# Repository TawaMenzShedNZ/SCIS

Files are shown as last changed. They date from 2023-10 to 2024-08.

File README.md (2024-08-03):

SCIS Shed Check-In System
===============

This is a management utility to track User signins / signouts and manage machine access.

(c) Tawa Menzshed 2024

Overview
-------------
This utility provides a central point for signing in and signing out of the workshop using RFID Fobs / Cards.
It also allows for Users' Fobs to be authorised to use equipment attached to a Device Access Box with a scanning mechanism.

Features
-------------
* Tracking of signins and signouts
* Database of Contact details for users
* Access Control for Devices attached
* Reporting on Access Dates / Times / Devices

Upcoming Changes
-------------
Enhancements coming for higher amperage Devices and better access management rules (sometime 2025).

Questions / Queries
-------------
Contact scistechnician49@gmail.com

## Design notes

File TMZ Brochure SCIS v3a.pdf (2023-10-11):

# Shed Check-In System

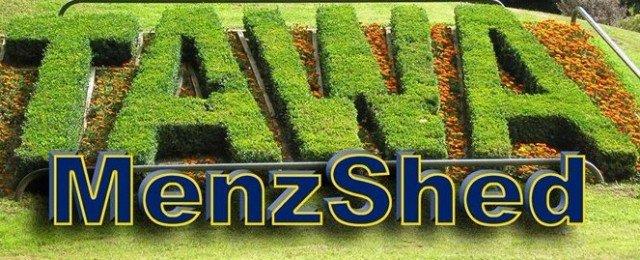
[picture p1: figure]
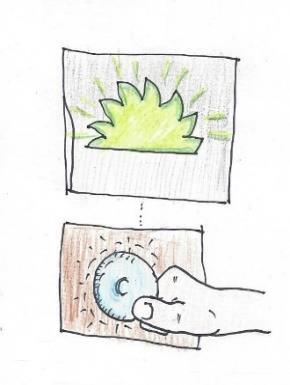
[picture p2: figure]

What is it? | A computerised System for tracking shed member attendance of Users, authorise member use of designated electrical equipment, identify when breakages occur and facilitate safety training.
Who can use it? | Any organisation that wants to know who is onsite, who is using machinery and what safety training is needed.
What does it use? | The system comprises 4 types of devices • a small PC for management • a sign-in box • one or more access boxes • a wireless router for communications

How does it work?

A small PC acts as a central server, and communicates with a sign-in device and one or more access boxes. The devices and boxes are using small Arduino computers which talk through the wireless router to the central server. Each Arduino has a swipe sensor reader to identify the user and validate their access. If a breakage occurs, the last user is known.

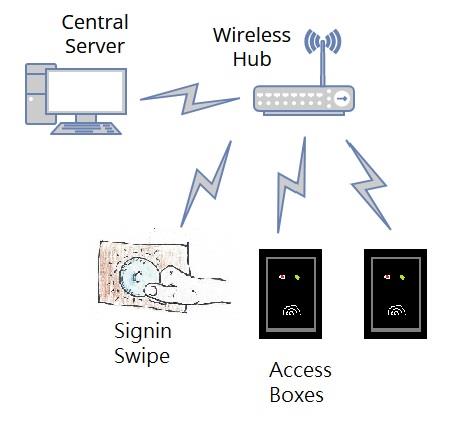
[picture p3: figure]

Would you like to know more?

Bookmark the github entry for the system at https://github.com/TawaMenzShedNZ/SCIS. An initial release of the code, build plans and documentation should be released in the first half of 2024.

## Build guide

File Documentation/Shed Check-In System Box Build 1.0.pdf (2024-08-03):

Shed Check-In System Access Box Build Procedure | Version 1.0

# Shed Check-In System Access Box Build Procedure

## Version 1.0

Author: Ian Dennison
Tawa MenzShed
Date: 07/07/2024
Version: 1.0

# Table of Contents

## Contents

# 1 Introduction

### 1.1 Document Purpose

This document describes the physical build and software installation of the Shed Check-In System (SCIS) Sign-In and Access Boxes.

### 1.2 Intended audience

This document is intended to be read and used by people with relevant technical knowledge (microelectronics, Arduino programming, and computer networking). Sheds wishing to implement this should seek out members or associates who have the required skills. For more details, refer Skills Requirement section in primary Shed Check-In System Manual.

### 1.3 Architecture

The SCIS Client Images are designed to run on WEMOS D1 Arduino Devices, with a built in WIFI component. Both the Sign-In / Sign Out Box and the Device Access Box are configured to run on these devices.

### 1.3.1 Sign-In Box

The Sign-in Box is a single box that is used for registering User sign-ins and sign-outs. It is also used to validate Administrators for access to the Admin functions of the System, so should ideally be placed near the Central Server.

### 1.3.2 Device Access Box

The Device Access Boxes are used for validating a User request and granting or denying access to a specific device (machine).

Each Access Box is identified by a unique identifier called a WWN, which is derived from the network chip on the Arduino device. This is matched up to the configuration inside the Central Server to provide access to the hardware attached to the Access Box.

When building the Device Access Box, your Power Relay will one of two types:

i) High – when the current applied is High, the access is opened

ii) Low – when the current applied is Low, the access will be opened

The current catered for at the moment is 10A, with a control voltage of 3.3V (matching the Arduinos voltages).

### 1.4 Preparation

### 1.4.1 Hardware Requirements – Sign-In Box

For the Sign-In/ Sign-Out Box, you will need the components listed in Appendix A. This box can be powered by a longer USB Cable connected to an external power supply (It may be possible to power it from a spare USB port on the Central Server itself).

Photo 1 – External View of Swipe Box

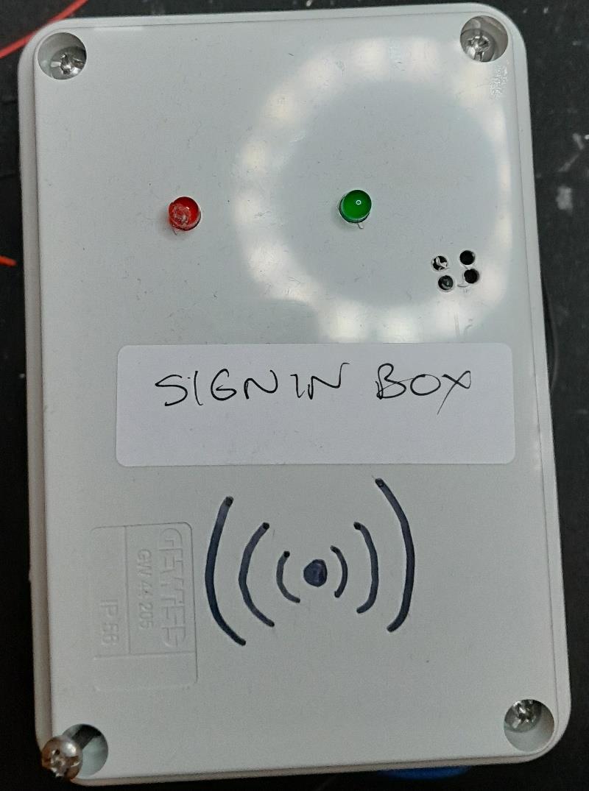
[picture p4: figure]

Photo 2 – Internal View of Swipe Box

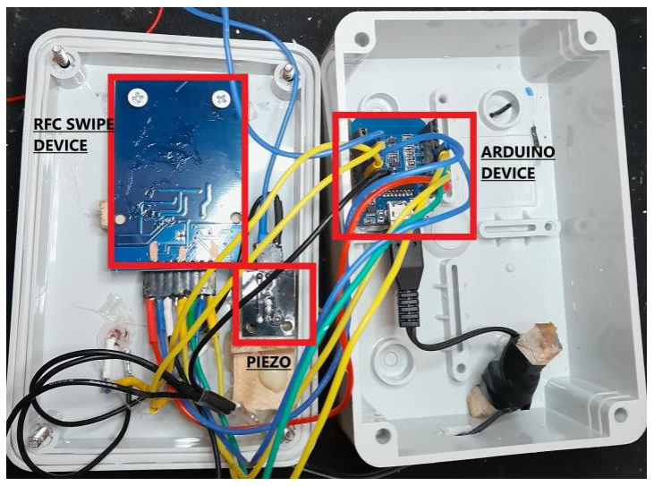
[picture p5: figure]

### 1.4.2 Hardware Requirements – Device Access Box

For the Sign-In/ Sign-Out Box, you will need the components listed at Appendix B.

The Device Access Boxes do involve more components so can compete for internal space. It is recommended to add an intermediate plug for the 2 x LEDs to allow the top of the device to be removed for maintenance. Also leave the bottom left area free, as future releases may use this space.

Photo 3 – Device Access Box (Top Cover)

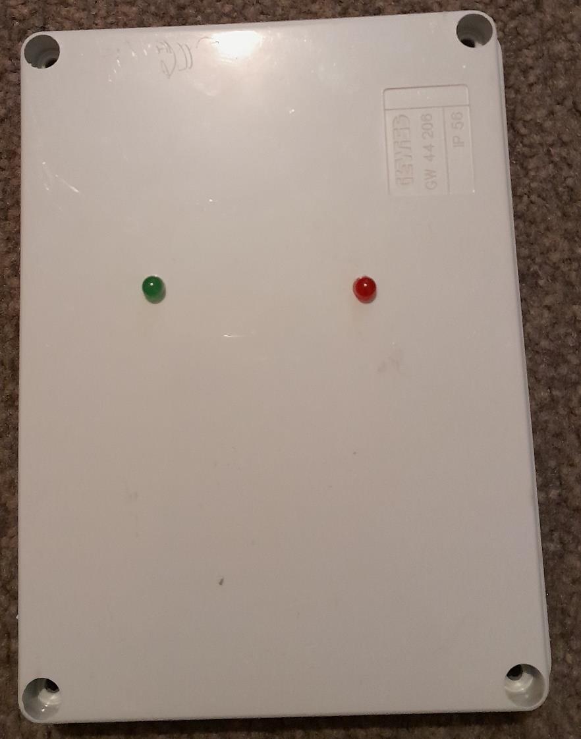
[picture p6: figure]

Photo 4 – Device Access Box (Top underneath)

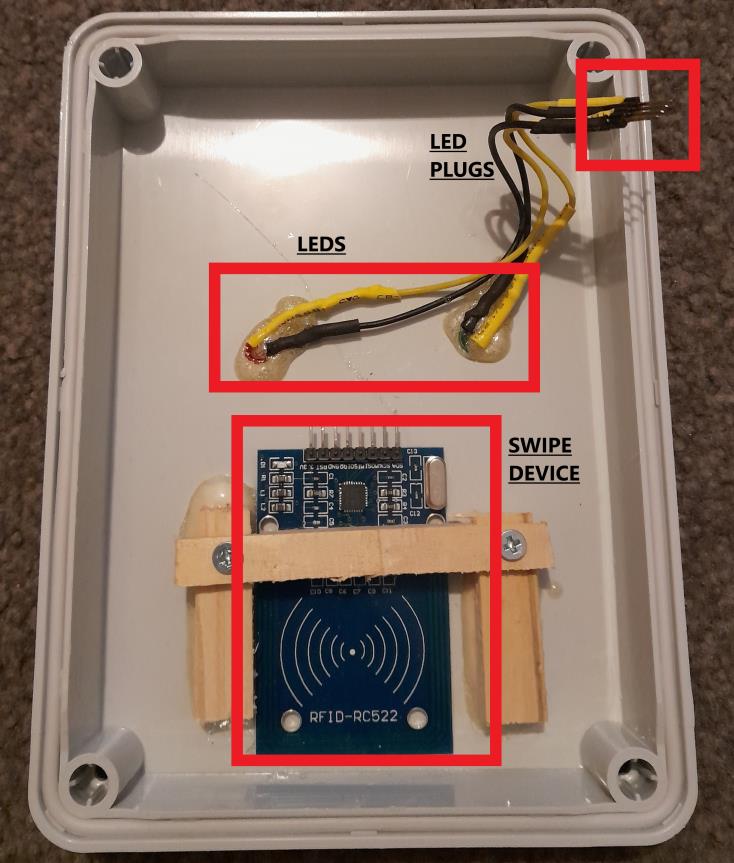
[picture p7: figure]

Photo 5 – Device Access Box (Body) – cables removed for clarity

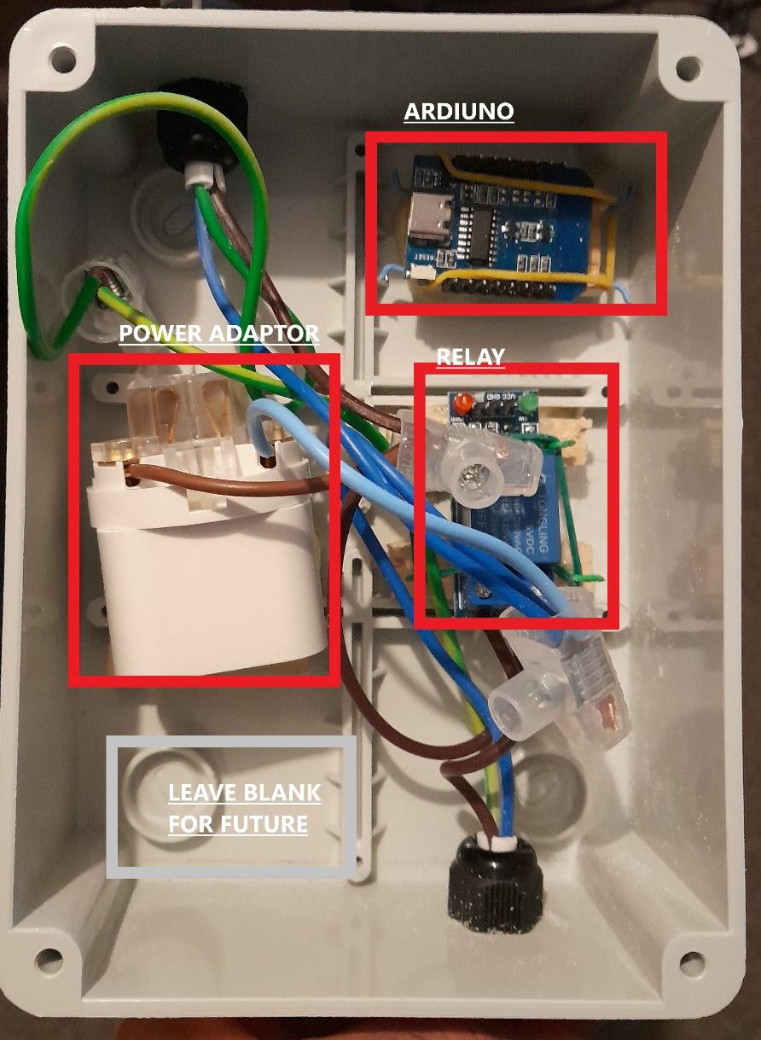
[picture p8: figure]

### 1.4.3 Software Requirements

There are 2 main images for the Device Access Arduino, depending on the type of Relay being deployed. At present, it is trial-and-error on which image is required, but an incorrect image should not damage the device (be sure to test before installing the Device Access Box).

Field | Rationale
machine_box_WWN_High.ino | Works on the WWN based addressing and activates Relay when current is High
machine_box_WWN_Low.ino | Works on the WWN based addressing and activates Relay when current is Low

In order to read the Wiring Diagrams for the Boxes, you will need the following software:….

i) Adobe Acrobat – This is the free reader application for PDF Files. It can be downloaded from https://get.adobe.com/reader/. It also comes bundled in newer web browsers.

ii) Fritzing – This circuit layout software is required if you wish to modify the .fzz sketches that are included as part of the Software Bundle and also included in PDF form for easy viewing. It can be downloaded from https://fritzing.org/.

To manage the Arduino devices and download the images and drivers, you will need the following software on a windows-based device.

iii) Arduino IDE – This is the software needed to manage the Arduino Devices and deploy the images to the Arduinos. It can be downloaded from https://www.arduino.cc/en/software.

### 1.5 Build

The attached PDF plans (taken from the Fritzing Images) should detail the layouts for cabling and connections, between the various components. Included are plans for Sign-in Boxes and Device Access Boxes.

This document assumes that you already know how to solder, cable and mount components to build an electronic project. A list of recommended tools and ancillaries are listed in Appendix D but are not exhaustive.

### 1.6 Good Practice Recommendations (Device Access Boxes)

- Power Cables – put these entry points offset from centre, to allow space for other electronics
| to fit in. Typically leave 60 cms of cable in for the plug end and 30 cms of cable to the socket end.
- Swipe Sensors – Place these hard up against the top cover of the box, even a gap of 5-8mm
| will make it difficult to read. Also mark the external location of the sensor to direct the user where to swipe.
- Wemos D1 – always purchase the variant with the requirement to solder the connectors, and
| chose the shorter as these fit the connectors better (longer pre-made connectors can push the connectors out of the surround).
- Relays – always connect incoming Phase Power Wire to “COM” (Common) and outgoing
| Phase Wire to “NO” (Normally Open).
- Relays – Always tin the wires that go into the control sockets of the relay for screw-down
| attachments.
- Relays – Option “H” should be selected on the Relay Jumpers.
- Mounting brackets – Wooden standoffs for securing components are cheap and easy to
| make. Future releases of this tool may include 3d printing patterns for custom mounting brackets.
- Connections – Use a hobby glue gun for components you may wish to remove and replace.
| For more permanent connections, it is recommended to use Tarzan’s Grip glue.

### 1.7 Software Deploy

### 1.7.1 Arduino IDE Software and Drivers

Download and install the Arduino IDE.

For Board Drivers, start the Arduino IDE on an internet connected computer and navigate to “File” – “Preferences. In the field “Additional Board Manager URLs:” add the entry http://arduino.esp8266.com/stable/package_esp8266com_index.json and close with OK.

Navigate to “Tools” – “Board” - “Boards Manager” and search for “esp8266” in the text field. Select the “Install” button.

Photo 6 – ESP8266 Package

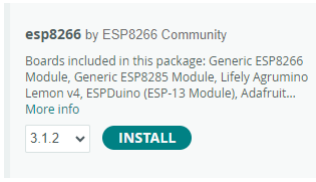
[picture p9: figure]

For Reader Libraries, select “Tools” – “Manage Libraries”. Enter the text “MFRC522” and select “Install” button.

Photo 7 – MFRC522 Package

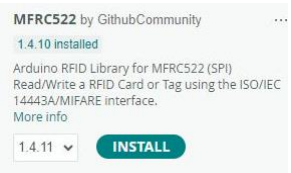
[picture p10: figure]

### 1.7.2 Customising the Arduino Image

In order to connect to your system, you will need to specify some of your local parameters.

Start the Arduino IDE and open the Image you wish to deploy using “File” - “Open” and selecting the relevant “.ino” file. You will need to update the following parameters…

Field | Rationale
ssid[] | The identifier of your Wifi Router
password[] | The password of your Wifi Router
port | Should stay at 80

Photo 8 – network parameters

### 1.7.3 Arduino Device Setup and Image Deploying

Start the Arduino IDE and connect the Arduino Device via USB.

Drop down the Board Box and you should see a COM Port assigned to the Device.

Photo 9 – Board Box Selection

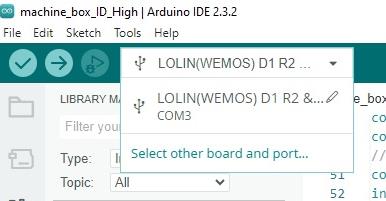
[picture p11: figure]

If it says “UNKNOWN”, click on the device and select Board Type of “LOLIN(WEMOS) D1 R2 & mini”.

To deploy the image to the Arduino, first open the image using “File” – “Open” and select the “.ino” file. Select the right arrow symbol on the toolbar to deploy the image (see above)

To monitor the output, the Serial Monitor needs to be open. Select the Magnifying Glass on the top

right of the screen to open this.

You will need to select the baud rate of the communications channel inside the Arduino, we recommend you use 115200. Otherwise you may see the response below.

Photo 10 – unprintable characters

You may need to perform a reset on the Arduino to see traffic (button next to USB connection).

### 1.7.4 Arduino Messages

The Arduino produces some messages not visible using normal operation but which can be viewed when connected to a Windows host with Arduino IDE installed.

Initial Setup

When starting up, the Arduino will alternately flash the LEDs until it can login to the Wifi. The messages below are a normal startup.

Photo 11 – normal startup

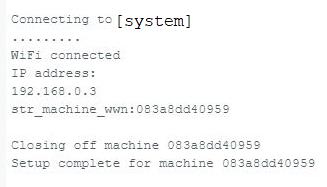
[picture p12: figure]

Access Denied

When a swipe is detected, the Arduino will send a web call to the Central Server with the Tag ID being swiped and the WWN of the Arduino, and the server will return a code of 0 for access denied or 1 for access approved. If no signal is received in 2-3 seconds, it will be assumed that access is denied.

Photo 12 – Access Denied

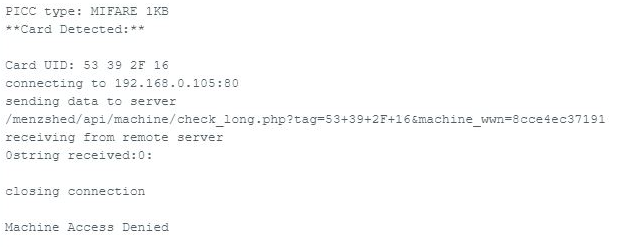
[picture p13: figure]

Access Accepted

When access is granted, the response from the Server will look similar to the text as follows…

Photo 13 - Access Granted

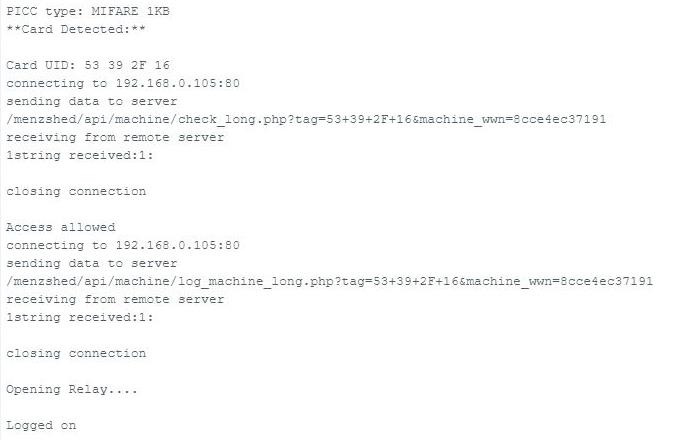
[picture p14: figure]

### Appendix A – Sign-in / Sign-out Box Hardware Components Recommendation and Costs

Component | Description | Indicative Cost
Arduino Device | Wemos D1 Mini with ESP8266 chip | $9 (Trademe NZ)
Swipe Device | RFID RC522 sensor kit | $20 (Trademe NZ)
USB Cable* | 2.0m Cable (check if Micro USB or USB-C, depends on model of Arduino) | $20 (most stores)
Enclosure | 155mm x 115mm x 75mm | $40 (J.A. Russell NZ)
Resistors | 2 x 150 Ohm resistor | $2 (Jaycar NZ)
LEDs | 1 x Red, 1 x Green (5mm, 20mA) | $4 (Jaycar nz)
USB Power | 5V 2A Mains Power Adaptor | $15 (PB Tech)

### Appendix B – Device Access Box Hardware Components Recommendation and Costs

Component | Description | Indicative Cost
Arduino Device | Wemos D1 Mini with ESP8266 chip | $9 (Trademe NZ)
Swipe Device | RFID RC522 sensor kit | $20 (Trademe NZ)
USB Cable* | 0.5m Cable (check if Micro USB or USB-C, depends on model of Arduino) recommend braided with small bend raduis | $20 (most stores)
Relay (3.3V 10A) | Capable of 240V AC, model BESTEP JQC3F-03VDC-C | $5 (epartners.co.nz)
Enclosure | 155mm x 115mm x 75mm | $40 (J.A. Russell NZ)
Resistors | 2 x 150ohm resistor | $2 (Jaycar NZ)
LEDs | 1 x Red, 1 x Green (5mm, 20mA) | $4 (Jaycar nz)
Power Cable | 2m extension cable | $4 (Bunnings NZ)
Enclosure (Power) | Arlec IP44 Outdoor Cord Safety Box | $4 (Bunnings NZ)
USB Power | 5V 2A Mains Power Adaptor | $15 (PB Tech)
AC Plug Socket | 3 pin 240V Female, For USB Power | $10 (Trademe NZ)

### Appendix C – Ancillary Tools / Supplies Required (not complete)

Component | Description

Soldering Iron

Soldering Station | With magnifying glass

Electrical Cable

Heat Shrink

Hookup Cable (24AWG)

240V insulated connectors

Wire Strippers

### Appendix D – Pictures of Common Parts

In order to prevent confusion when ordering online, the required images are shown for the required components.

Component | Image

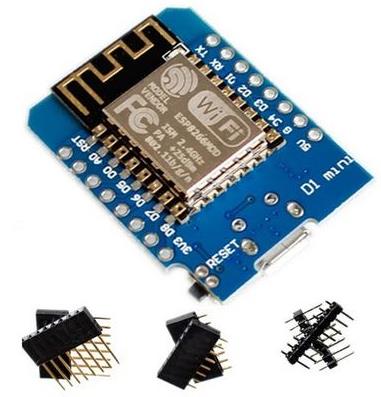
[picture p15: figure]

WEMOS D1 Arduino Device

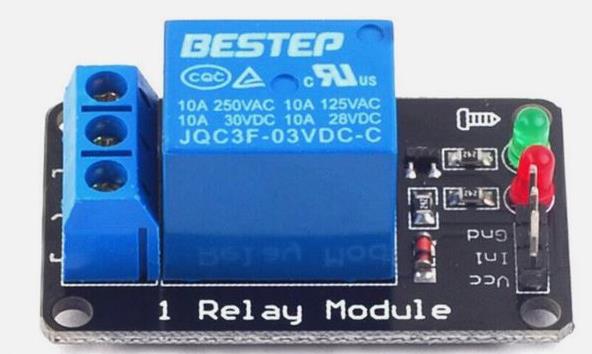
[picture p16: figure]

3.3v 10A Relay

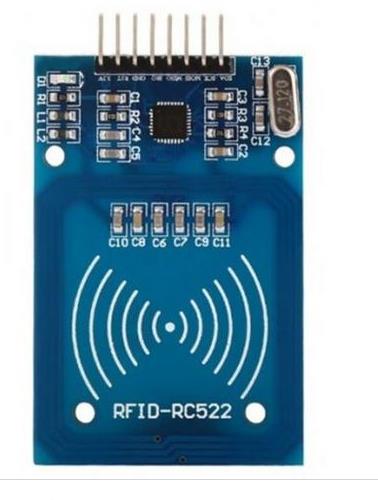
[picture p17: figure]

RFID RC522

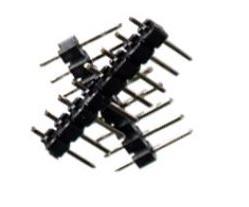
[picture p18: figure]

Shorter Male Prongs (recommended)

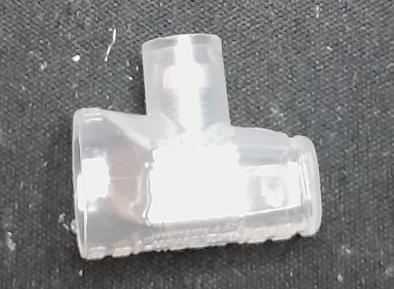
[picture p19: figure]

240V electrical connector

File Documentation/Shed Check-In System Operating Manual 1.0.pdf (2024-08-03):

Shed Check-In System Operating Manual | Software Version 1.0
Page | 1 of 21

# Shed Check-In System Operating Manual

## Software Version 1.0

Author: Ian Dennison
Tawa MenzShed
Date: 07/07/2024
Version: 1.0

Shed Check-In System Operating Manual | Software Version 1.0
Page | 2 of 21

# Document Information

# Table of Contents

# Contents

Shed Check-In System Operating Manual | Software Version 1.0
Page | 3 of 21

Shed Check-In System Operating Manual | Software Version 1.0
Page | 4 of 21

# 1 Introduction

### 1.1 Document Purpose

This document describes the management and use of the Shed Check-In System (SCIS) version 1.0, released on 7/7/2024.

### 1.2 Intended audience

This document is intended for Administrators who wish to use the features of System Checkin / Checkout and Device Access Control on their environment.

A working knowledge of IT systems (Command Line, Web Browser Usage, Networking) is required for managing this System

### 1.3 System Purpose

The Shed Check-In System is an attendance register and machine access management system that automates attendance recording, machine access authorisations and actual machine access.

By maintaining the access register, an Administrator can record machine usage, confirm user attendance and control machine access. This can be used to ensure adequate training on equipment before it is used, and providing accountability in the event of damage or abuse of equioment.

### 1.4 System Architecture

The Shed Check-In System uses a Client / Server architecture. It maintains a record of Member Details, Access Box Details, Access Permissions and Sign-in / Sign-out actions. It uses wireless technology to communicate between the Access Boxes and Central Server.


Shed Check-In System Operating Manual | Software Version 1.0
Page | 5 of 21

### 1.4.1 Central Server

This is a Unix Host running an Apache Web Server and MySQL Database. It manages the function of tracking sign-ins and authorisations for usage of Machines.

### 1.4.2 Signin / Signout Swipe

This is a wireless Arduino device with an RFC Reader that interfaces with the Central Server to record sign-ins and sign-outs. There should only be one Signin Swipe per system and it should be co-located with the Central Server where-ever possible.

### 1.4.3 Access Boxes

These are wireless Arduino devices with an RFC Reader and a Power Relay, that enables or disables power to the connected Tool. These can be identified by a Device ID, or the unique Device WWN derived from the Network component of the Arduino device.

There are 4 basic images that the Access Boxes may use are:

Field | Rationale
machine_box_WWN_High.ino | Works on the WWN based addressing and activates Relay when current is High
machine_box_WWN_Low.ino | Works on the WWN based addressing and activates Relay when current is Low

The “WWN based addressing system” is where the Device ID / Machine ID is assigned at the Central Server, but a link is made between the Device ID on the Server and the unique WWN of the Device Access Box. This allows the same Arduino image to be used on all Device Access Boxes and for swapping of Boxes to be performed by an Administrator rather than requiring a Technician.

### 1.4.4 Network Router

This is a Home Hub device designed to provide IP Addresses and wireless connection between Arduino devices and the Central Server.

### 1.5 Definitions

Term/Acronym | Definition/Full Description
DHCP | Dynamic Host Control Protocol.
DNS | Domain Name System.
Fob | An RFID device (usually round) that is used to identify a User. An alternative to a swipe card..
FQDN | Fully Qualified Domain Name.
HTML | HyperText Markup Language.
MD5 | Message Digest. Used to verify data integrity of the CDSF, and during the initial DSMS System deployment.
NTP | Network Time Protocol.
Perl | A computer programming language
RHEL | Red Hat Enterprise Linux.
root (userid) | The super-user / administrator userid on the Linux system

Commented [JB1]: Sorted table alphabetically by term

Shed Check-In System Operating Manual | Software Version 1.0
Page | 6 of 21
SFTP | Secure File Transfer Protocol. A secure method of file transfer between two systems. SFTP is a subsystem of SSH.
SSH | Secure Shell. A secure method of communication between two systems.
Swipe Card | An RFID Device (usually white and flat) used to identify a User. An alternative to a fob.

Shed Check-In System Operating Manual | Software Version 1.0
Page | 7 of 21

# 2 Installation

### 2.1 System Requirements

### 2.1.1 Host Server Requirements

The SCIS System is made from a collection of common components and requires a common system to run it, often referred to as a LAMP stack - that is, Linux, Apache, MySQL, Perl. The System Requirements below should therefore be considered as confirmed working defaults rather than minimum requirements. Depending on the computing equipment available to you and your level of knowledge, you may wish to use alternative configurations.

### 2.1.1.1 LinuxLite

The system is known to work on Linux Lite 6.4 (Website https://www.linuxliteos.com/index.html). This release is free for non-commercial use. The Linux operating system will require an active internet connection to download any additional software while the Application is installed. After that, it is recommended to host the system on a dedicated network with no connection to the wider internet.

You will require root access on the DSMS Server for the initial setup.

### 2.1.1.2 Apache 2

Apache, due to its widespread use and stability, is the only web server that the SCIS Application has been tested and confirmed working on. Apache 2 should be installed from your distribution’s base repository. No support is offered for alternative configurations..

### 2.1.1.3 Mysql (aka Mariadb)

Mysql is a relational database product that can store data as used by SCIS. Mysql should be installed from your distribution’s base repository.

### 2.1.2 Tarball Contents

A custom script is used to deploy the tool, and this is combined into a “tarball” along with the necessary Web Files and Database schemas.

Directory | Contents
./ | Basic install scripts
./var_www_html | Web pages and scripts
./mysql | Database Creation Scripts

### 2.1.3 Skills Requirements

Some technical skills will be required to install the SCIS System and build and deploy the Swipe System Boxes.

Skill | Requirement
Computer – Hardware | Procuring and Assembling Hardware Managing Boot Process Basic Network / Router Configuration
Computer – Software | Navigation of Menu and File Paths Modification of Files

Shed Check-In System Operating Manual | Software Version 1.0

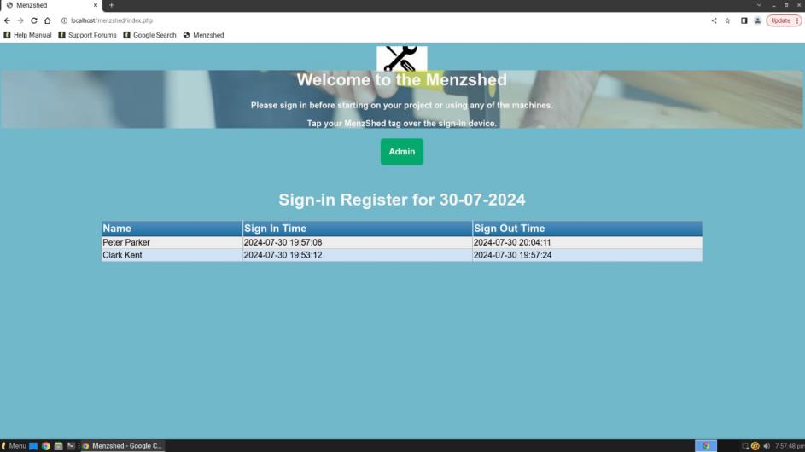
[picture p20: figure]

Page | 8 of 21
| File Transfer and Session Management
Electronics | Component Identification Soldering and Cabling
Electrical | Wire Stripping and Connection Cabling standards

WARNING! Electrical work is covered by different codes in different administrative environments. Make sure you adhere to the rules for your jurisdiction. Electricity can kill!

### 2.2 SCIS Central Server Installation

See separate documentation for SCIS Server Installation.

### 2.3 SCIS Signn and Device Access Box Setup

See separate documentation for SCIS Sign In and Device Access Box Installation.

### 2.4 SCIS Administration

### 2.4.1 Initial Setup

Once the Application has installed, login to the Server itself, start your web browser and navigate to the site http://localhost/menzshed/. You should be presented with the following screen which shows logins and logouts for the current day.

Clicking on “Admin” will take you to the validation screen

Shed Check-In System Operating Manual | Software Version 1.0

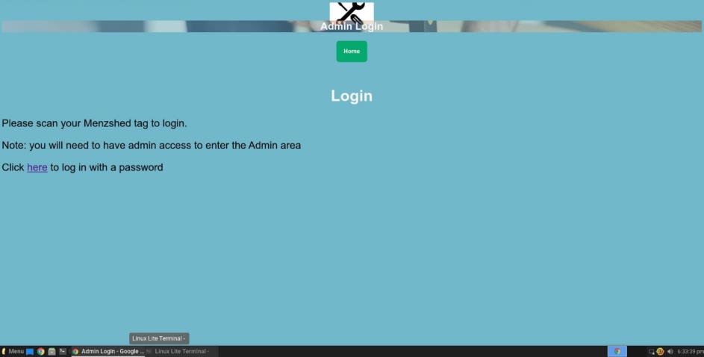
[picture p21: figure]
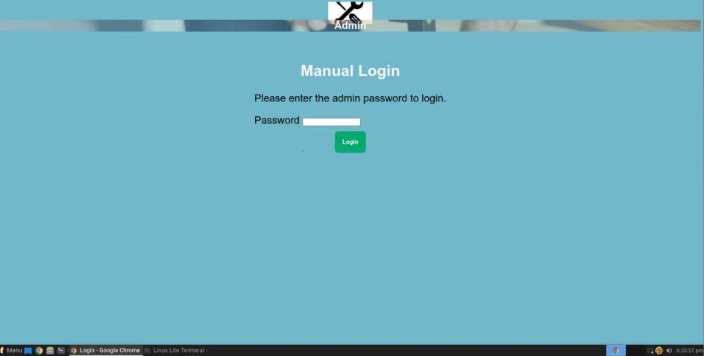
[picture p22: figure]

Page | 9 of 21

Enter your 4 digit passcode from the installation. If you have set up Users already with Administration rights, they can swipe on the signin box instead to gain access.

This is the default Admin Screen presented.

### 2.4.2 Default Administration Screen

This is the main administration screen where the System can be maintained. It is made up of the Header area (where the icons are shown), the Body area where content is displayed, and the Footer area where messages are displayed.

Shed Check-In System Operating Manual | Software Version 1.0

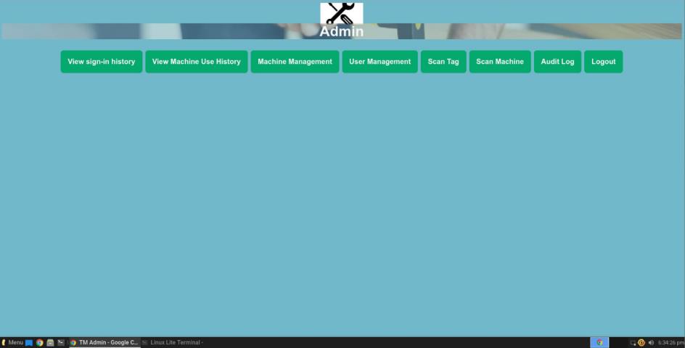
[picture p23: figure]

Page | 10 of 21

The areas are as follows…

Option | Description
View sign-in History | Provides list of sign-ins and sign-outs for users
View Machine Use History | Shows the machine usage log for users, including failed attempts at access
Machine Management | Management of Machine Configuration
User Management | Maintenance of Users and their rights
Scan Tag | Used to identify Tag IDs
Scan Machine | Allows identification of Access Box WWNs
Audit Log | Display logs of machine current load levels (not enabled in this version)
Logout | Logs out the Administration User from the session

### 2.4.3 User Administration

Select the “User Management” icon to display the User Administration screen. This will show a list of current users with a summary of their information.

Shed Check-In System Operating Manual | Software Version 1.0

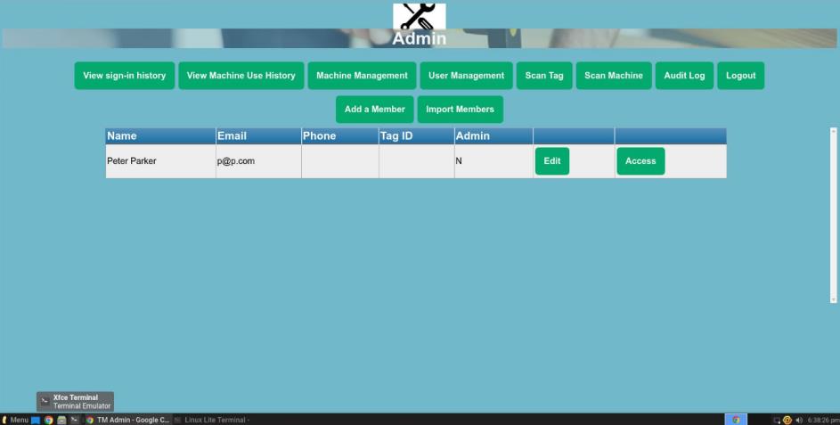
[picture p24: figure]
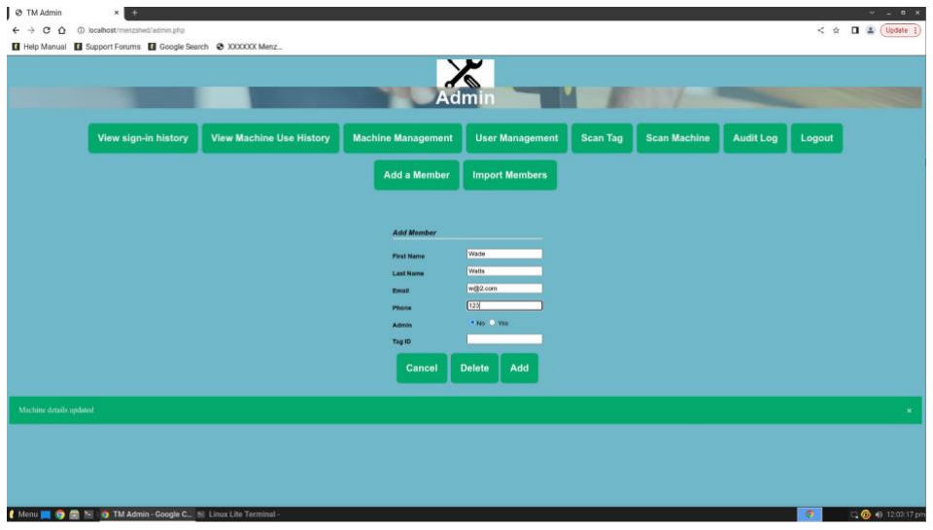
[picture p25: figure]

Page | 11 of 21

### 2.4.3.1 Adding a User

Select the “Add a Member” icon and the following screen will be displayed.

The following fields will be displayed:
- First Name: The First Name of the User
- Last Name: The Last Name of the User
- Email: The Email Address of the User (optional)
- Phone: The Phone Number of the User (optional)
- Admin: Whether the User is an Administrator or not
- Tag Id: The Tag ID of the User (to be filled in later)

Select the “Add” Icon to add the user to the system.

Shed Check-In System Operating Manual | Software Version 1.0

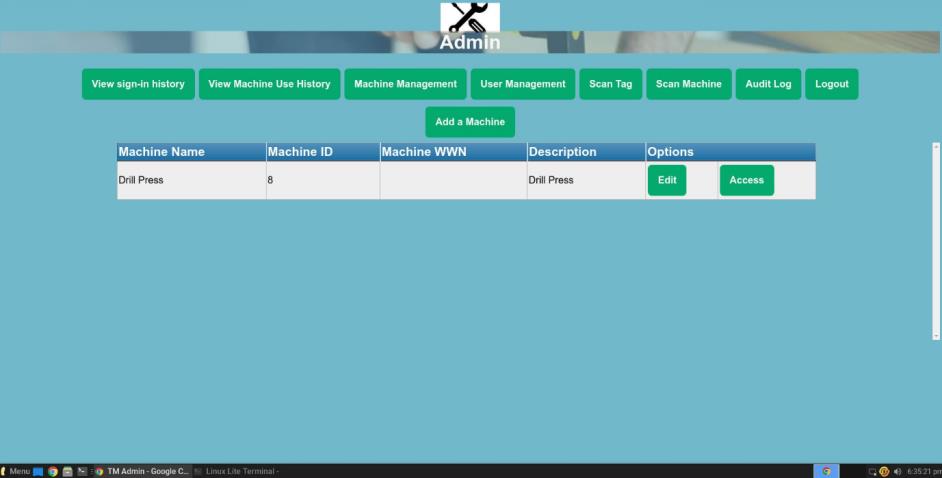
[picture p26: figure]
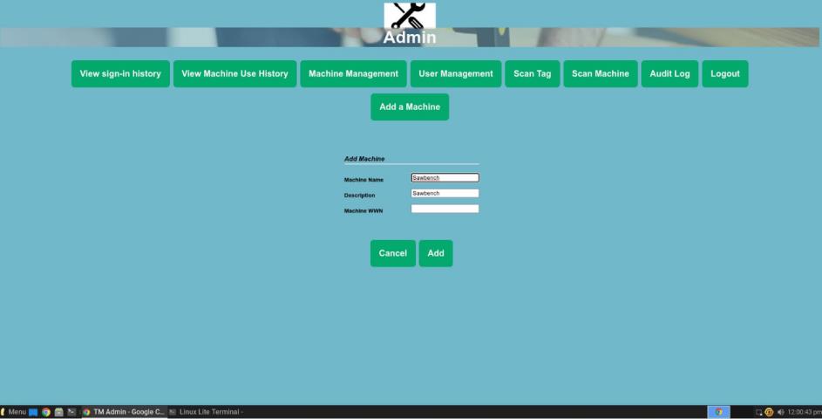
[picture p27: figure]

Page | 12 of 21

### 2.4.3.2 Modifying a User

To modify the User, select the “Edit” icon on the list of Users under “User Management”. The same screen for adding should be displayed with the existing values. Select “Update” icon to confirm the changes.

### 2.4.3.3 Deleting a User

To delete a User, select the “Edit” icon on the list of Users next to the required User, and select the “Delete” icon.

### 2.4.4 Machine Administration

To display the Machine Administration screen, select the “Machine Management” icon from the header.

### 2.4.4.1 Adding a Machine

To add a Machine, select the “Add a Machine” icon. You will be presented with the following screen.

Shed Check-In System Operating Manual | Software Version 1.0

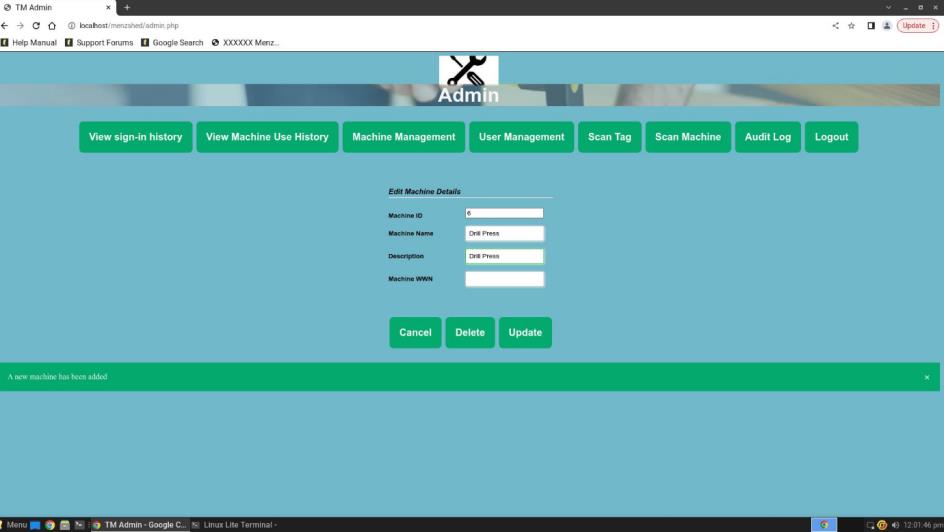
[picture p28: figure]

Page | 13 of 21

The following fields will be displayed:,….
- Machine Name: The name of the Machine
- Machine Description: Long form name of the Machine
- Machine WWN – The unique ID of the Access Box connected to the Machine (optional)

To add the Machine, select the “Add” button.

### 2.4.4.2 Modifying a Machine

To modify a Machine, select the “Edit” button on the Machine List, you will be presented with the following screen. Now the machine is present, the Machine ID will also be displayed.

### 2.4.4.3 Deleting a Machine

To delete a Machine, select the “Edit” button next to the machine and the “Delete” button on the Edit screen.

### 2.4.5 User and Machine Registration

### 2.4.5.1 User Registration

To assign a Swipe Card or Fob to a User, logon as an Administrator to the Central Server and select the “Scan Tag” button.

You will be presented with the following screen.

Shed Check-In System Operating Manual | Software Version 1.0

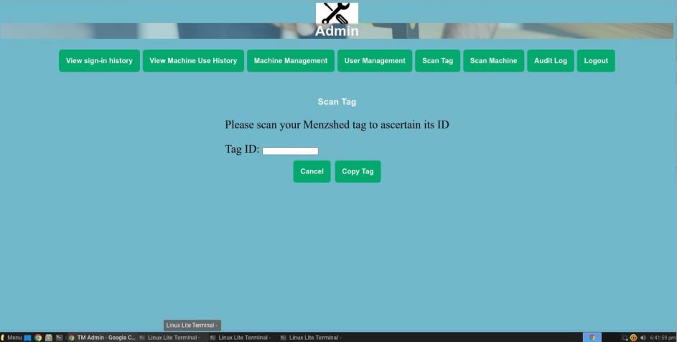
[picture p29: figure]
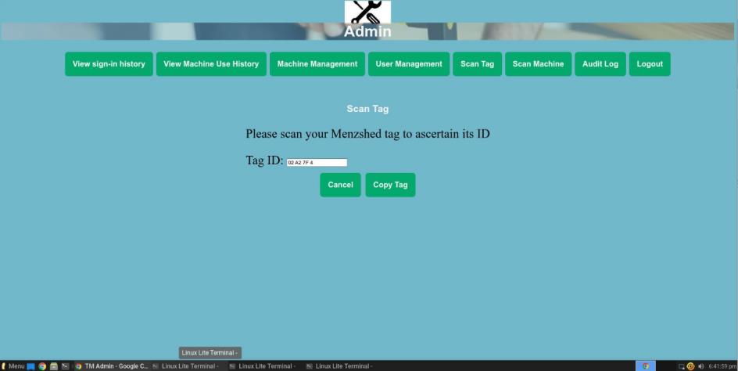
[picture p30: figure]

Page | 14 of 21

On the Sign-in Box, swipe the Fob to be assigned. After a 1-2 second interval, the unique ID of the Fob will be displayed on the screen. Select the “Copy Tag” button to copy the Tag ID into memory.

Navigate to the User using the “Edit” function of the “User Management” screen. You can then paste the copied ID to the “Tag ID” field using keys [Control]-V, and update the User with the “Edit” button.

Shed Check-In System Operating Manual | Software Version 1.0

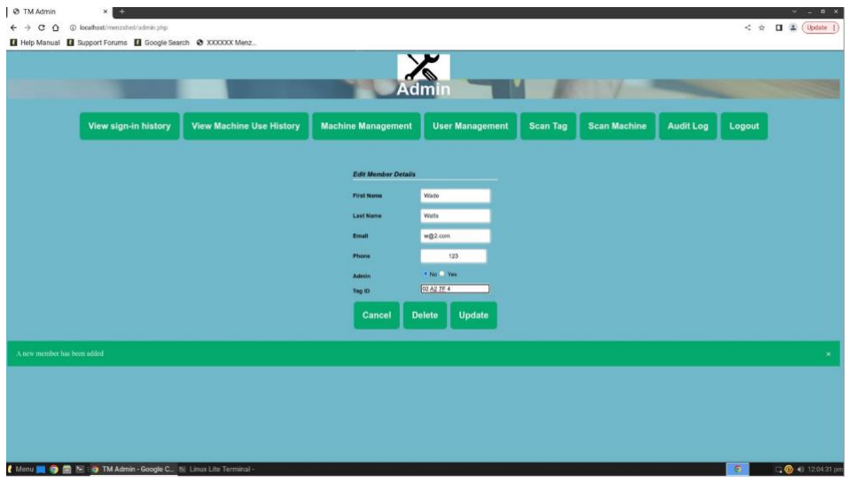
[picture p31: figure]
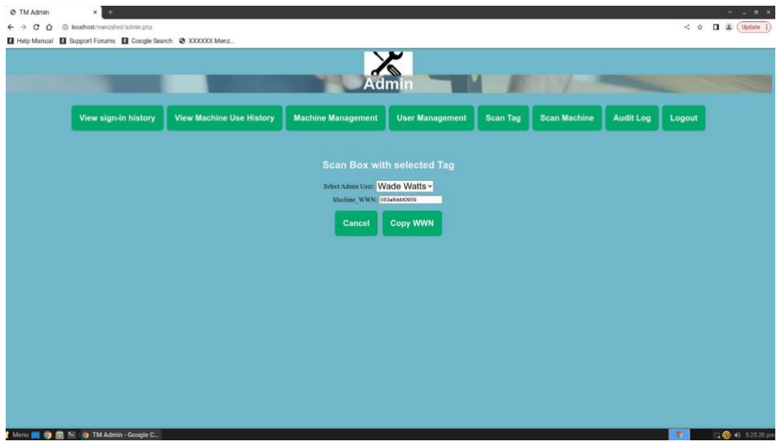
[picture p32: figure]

Page | 15 of 21

### 2.4.5.2 Machine Registration

NOTE: This only applies if using a WWN based image on the Device Access Box.

Log into the Admin Area using an Administrator Fob, and navigate to the “Scan Machine” Screen. From the drop-down box, select the Administrator whose tag will be used to identify the Device Access Box. Once this is selected, the screen will refresh every 2 seconds with the latest Device that the Administrator has swiped against.

To place the Machine WWN discovered into the Copy buffer, select the “Copy WWN” button.

Now navigate to the Machine Management screen and “Edit” the required machine. Paste the WWN into the “Machine WWN” field using [Control]-V and select “Update”. The system will validate the WWN and if it is used elsewhere, it will prevent you from committing the update.

Shed Check-In System Operating Manual | Software Version 1.0

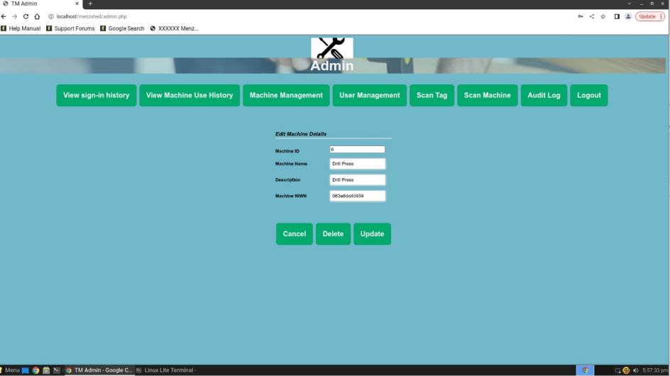
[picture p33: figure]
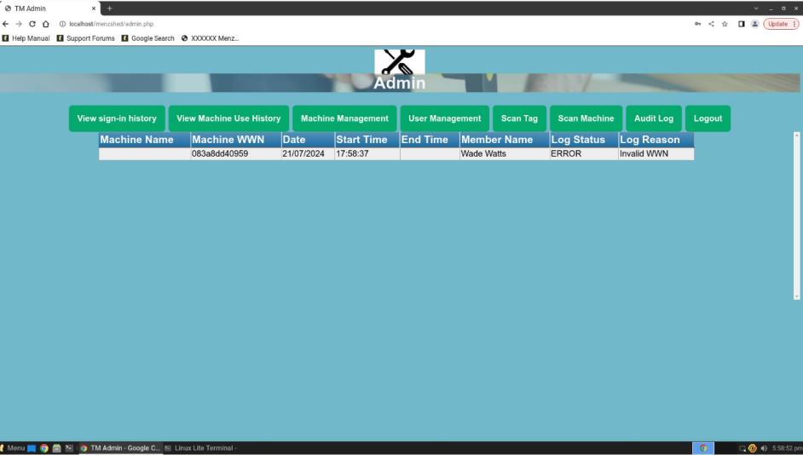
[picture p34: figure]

Page | 16 of 21

NOTE: If the Device Access Box is previously unknown to the System, you will see an error message in the Machine Use History for “Invalid WWN”, similar to the one below. This is expected behaviour and more will be explained on error codes later in this document.

### 2.4.6 Sign in / Sign Out

To sign in, ensure the Server Console is out of Administration Mode and showing the Sign in Screen. By swiping your Fob against the Sign In Sensor, you will be logged in, or (if already logged in), logged out. The screen will be refreshed every 2 seconds with the latest information.

Shed Check-In System Operating Manual | Software Version 1.0

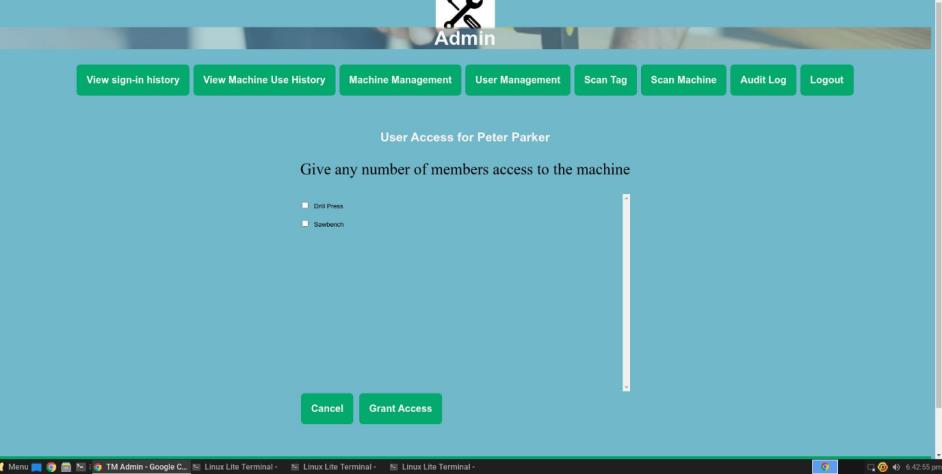
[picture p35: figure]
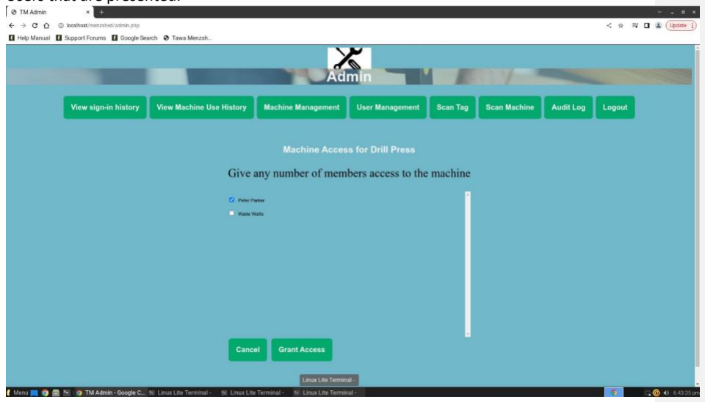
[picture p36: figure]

Page | 17 of 21

### 2.4.7 Access Granting

Access can be granted for Users to operate Machines in 2 separate ways. Both update the same backend Database, so any changes in one will be reflected in the other.

### 2.4.7.1 Machine based Access Granting

If you navigate to the User Management Menu, and select the “Access” against the Icon of the relevant User, you can grant or deny access to the Machines defined in the system. Select the “Grant Access” icon to submit the changes.

### 2.4.7.2 User based Access Granting

### To grant access to specific Users, navigate to the Machine Management screen and select the “Access” icon next to the relevant Machine. You can then add or remove rights for the

Users that are presented.

Shed Check-In System Operating Manual | Software Version 1.0

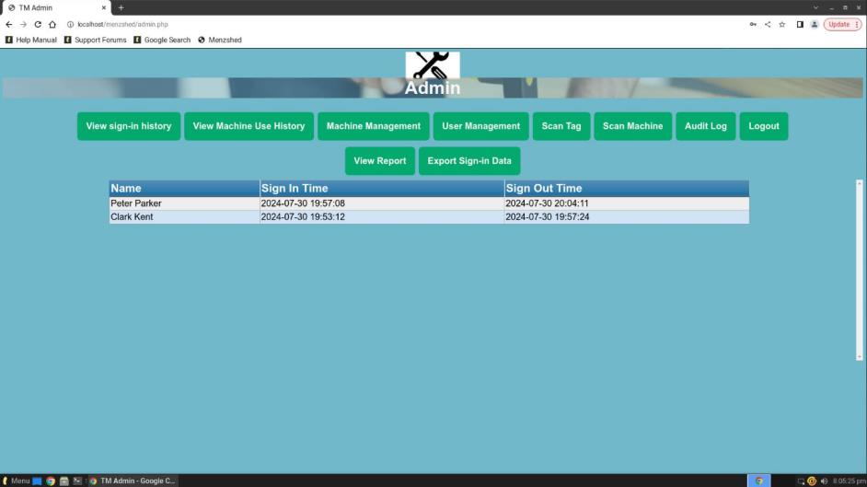
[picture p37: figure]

Page | 18 of 21

### 2.4.8 Device Swapping

### If you are using the WWN variant of the Access Box Image, you can use the “hot swap”

capability.

### To replace a broken Device Access Box, swipe the new Device Access Box using the “Scan Machine”, then paste that into the

### 2.5 SCIS Error Codes and Troubleshooting

### 2.5.1 Sign-in Logs

To review the sign-in logs, select the “View sign-in history” button from the main screen.

### 2.5.2 Machine Logs

There is a set of Audit Logs for Machine use, which can be viewed using the “View Machine Use History”

Shed Check-In System Operating Manual | Software Version 1.0

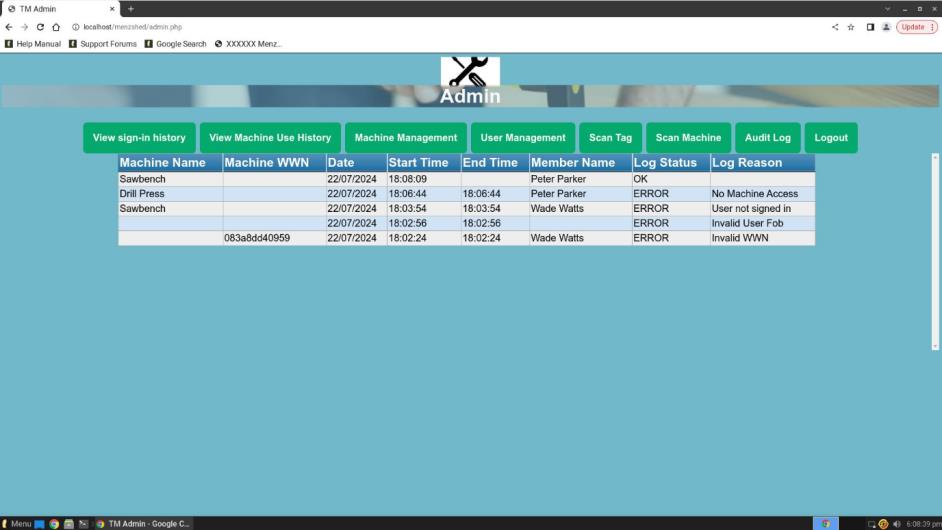
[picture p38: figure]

Page | 19 of 21

For a successful Machine Access, the “Log Status” field will show “OK” and the Start and End Date will indicate when the power was enabled and disabled for the Device Access box.

The other error related messages are as follows…

Error | Description
Invalid WWN | Someone has attempted to use a WWN-based Device Access Box, either as an Administrator scanning a box, or a user attempting to use an unknown box.
Invalid User Fob | A swipe action has been performed with a Fob or Card not known to the system.
User not signed in | A valid User has attempted to use a Machine but has not yet swiped in.
No Machine Access | The User is presenting a valid Fob and has signed in but is not authorised to use the Machine.

### 2.5.3 Access Box Troubleshooting

When initially starting up, a Device Access Box will alternate the Green and Red Leds until it successfully registers with the Server, at which point the Red Led will be constantly on.

When a swipe attempt has been successfully made and approved, the Green LED will be lit.

When a swipe attempt has been successfully made and rejected, the Red LED will flash once and then return to being constantly on.

Sometimes a Device Access Box will not read a swipe action, in which case you should retry 2-3 times about 2-3 seconds apart. The best results come from swiping across the face of the sensor area and against the body of the Access Box.

If no response is still forthcoming, you may need to power cycle the Device Access Box.

It is recommended after usage is finished to power down the Device Access Box.

Shed Check-In System Operating Manual | Software Version 1.0
Page | 20 of 21

A Device Access Box will normally provide 30 mins of access at which time it will disable the Power connection. This will happen at the 30 minute point even if the machine is in use. Future releases are planned to detect this situation and provide a more orderly shutdown process.

### 2.5.4 Administration Gui Troubleshooting

### Sometimes when the Scan Tag or Scan Machine tasks are used, they can remain active and

background and take over the screen. The way to block this when it happens is to press F5 (on the keyboard) to refresh the screen. This should have been detected and corrected in the code, please alert via the email address if you continue to see this.

### 2.5.5 Community Forums

While there is no community forum for the SCIS system, you can query the technical staff at scistechnician49@gmail.com on issues related to the SCIS code or highlight any bugs you find. This will be on an as-available basis, and may not necessarily be able to resolve your issue.

Alternatively, there are several excellent public forums for assisting in resolving issues…

### https://www.arduino.cc/ - Useful for Arduino related issues (including hardware setup)

https://stackoverflow.com/ - Provides coding and technical advice on web services and linux.

### 2.5.6 Copyright and Licensing

This suite of Programs is released under the GNU General Public License. The basic rules are as

### follows: - You may use this software for any purpose (commercial or private) - This software must be distributed with all its code available to view / modify - This software must be made available for no cost

- If you modify this software, you must credit previous contributors to it.
- If you wish to distribute modified versions of this software, you must follow all the rules in this list.

### For detailed information, visit the website https://www.gnu.org/licenses/licenses.html

This software is distributed without any warranty or guarantee and is used at the owner’s risk.

Shed Check-In System Operating Manual | Software Version 1.0
Page | 21 of 21

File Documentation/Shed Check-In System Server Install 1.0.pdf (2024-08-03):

Shed Check-In System Central Server Install Procedure | Version 1.0

## Shed Check-In System Central Server Install Procedure

### Version 1.0

Author: Ian Dennison
Tawa MenzShed
Date: 07/07/2024
Version: 1.0

## Document Information

## Table of Contents

## Contents

## 1 Introduction

### 1.1 Document Purpose

This document describes the installation of server software for the Shed Check-In System version 1.0, released on 7/7/2024.

### 1.2 Who this guide is for

This guide is intended for Administrators who wish to set up a Shed Check-In System and utilise the features it provides (User Checkin/Checkout and Device Access Control).

### 1.3 Preparation

### 1.3.1 Hardware Requirements

You will need to have cabled up the Central Server to an active Internet Connection, by using a physical port, or alternatively if the Server has a wireless capability, you can add this connection during the install phase. The Monitor, Keyboard and Mouse will need to be correctly connected. You will also need to know how to interrupt the boot sequence of your server and select a bootable device. Your server will need to able to boot from an USB Device.

For LinuxLite Install, you will need a memory stick of at least 4GB capacity, and a separate Internet Connected Host to download and burn the image.

### 1.3.2 Software Requirements

You will need to download the ISO image for LinuxLite 6.4, which will be approx. 3.5GB in size. Download the latest tarball image from the github website. You will also need to download an ISO Image Burner (We recommend BalenaEtcher from https://etcher.balena.io/).

### 1.4 Setup

To download the Linux Lite image, visit https://www.linuxliteos.com/mirrors.php and select the link in the “Download” column nearest to you. Select the “6.4” directory and click on the “linux-lite-6.4-64bit.iso”.

Place a blank USB Memory Stick in a PC and use the BalenaEtcher tool to write the Linux Lite Image to the Memory Stick.

To download the Installer for SCIS, right click on the file “tmz_[version].tar.gz” and select “Save Link as”.

Setup your dedicated modem, with the following values (configuration methods vary greatly so no screenshots provided).

Field | Value | Rationale
Router IP | 192.168.0.1/24 | Primary IP of the Router and Gateway for the Server
DHCP Service | Enabled | Allow provision of IP Addresses
DHCP Range | 192.168.0.2-99 | IP Address ranges serviced by DHCP

### 1.5 Installation of Operating System

If you are using hard-wired internet, connect this now to the Server.

Boot the Server and interrupt the boot sequence at the appropriate time (example shown is Intel NUC).

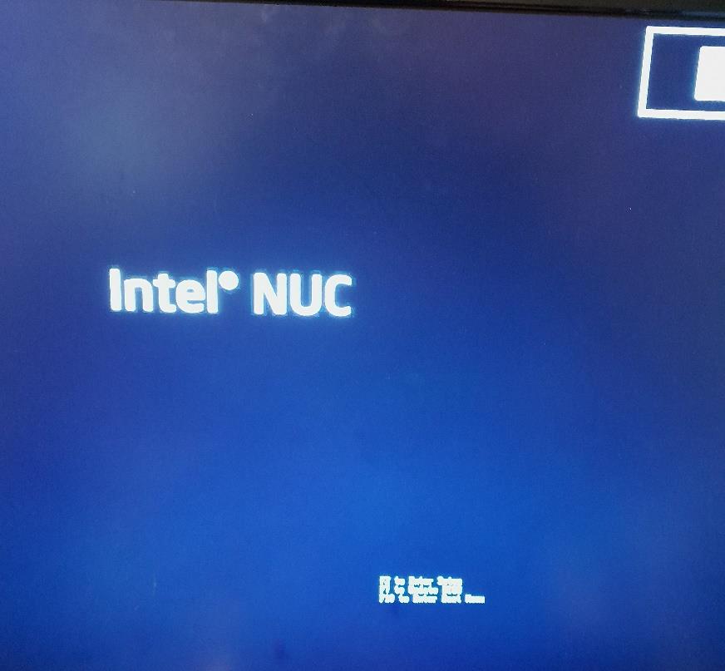
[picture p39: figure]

Select the USB Device to boot from (Example Image is from the Intel NUC)

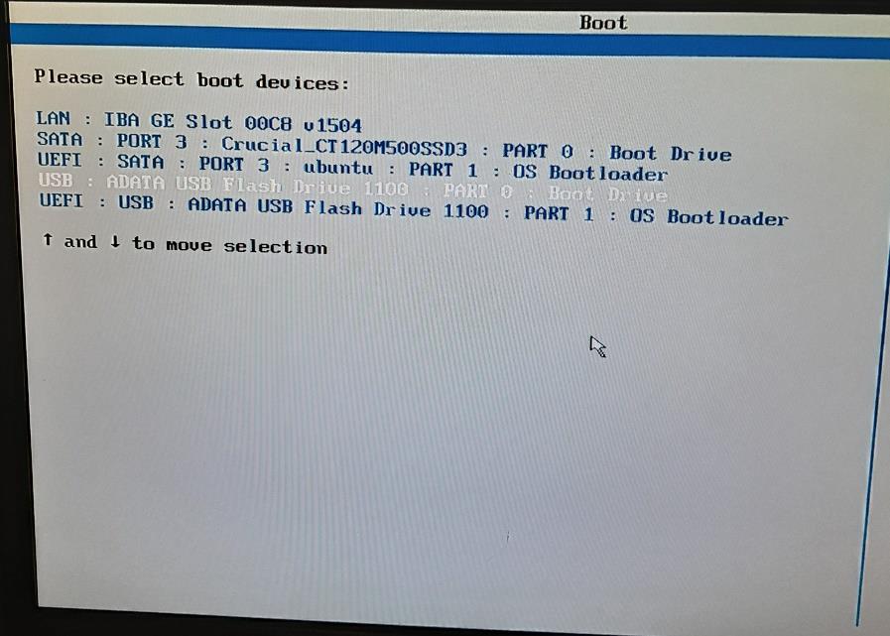
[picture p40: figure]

Select the “Direct Install” option presented and press Return.

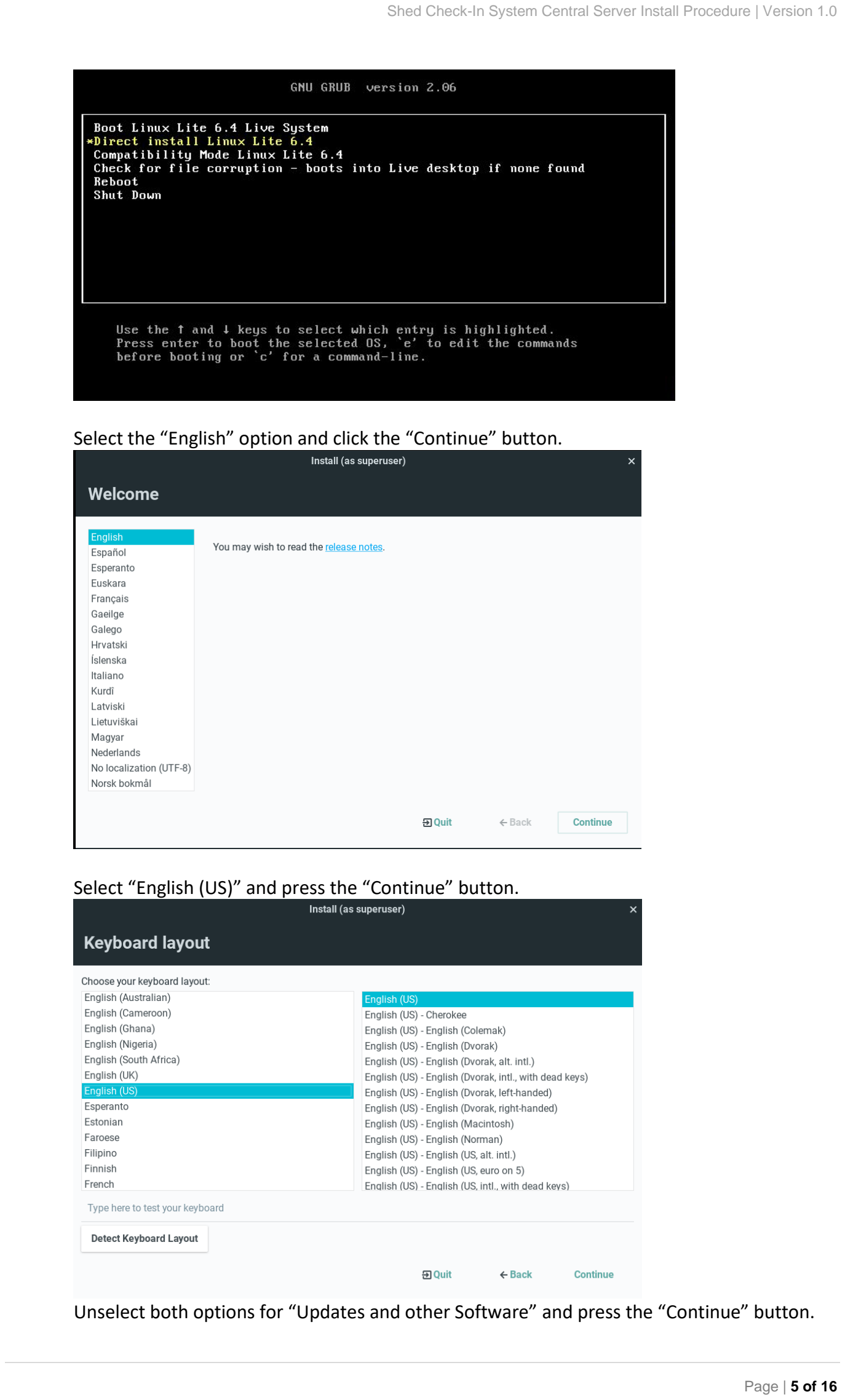
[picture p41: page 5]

Select the “English” option and click the “Continue” button.

Select “English (US)” and press the “Continue” button.

Unselect both options for “Updates and other Software” and press the “Continue” button.

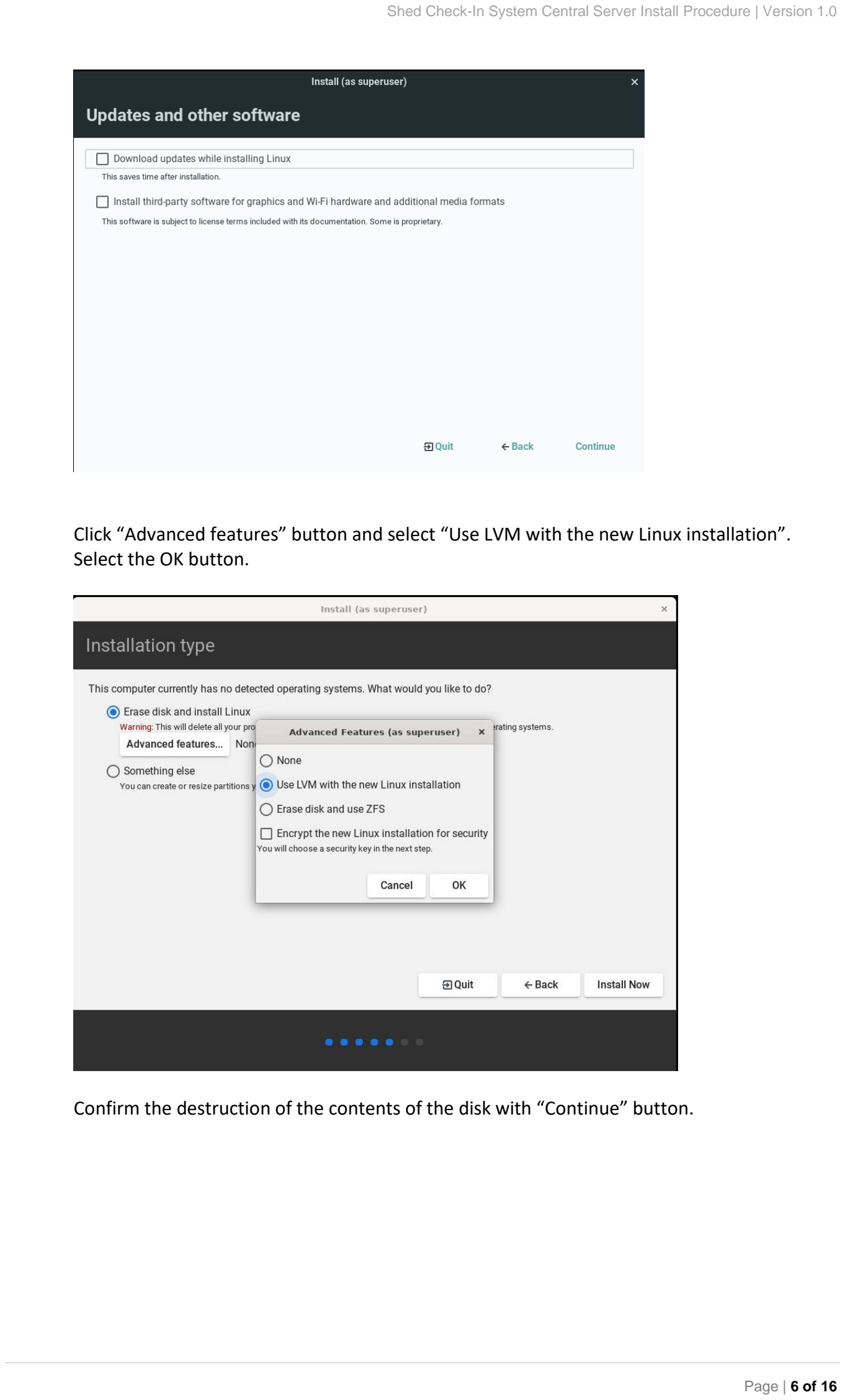
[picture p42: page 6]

Click “Advanced features” button and select “Use LVM with the new Linux installation”. Select the OK button.

Confirm the destruction of the contents of the disk with “Continue” button.

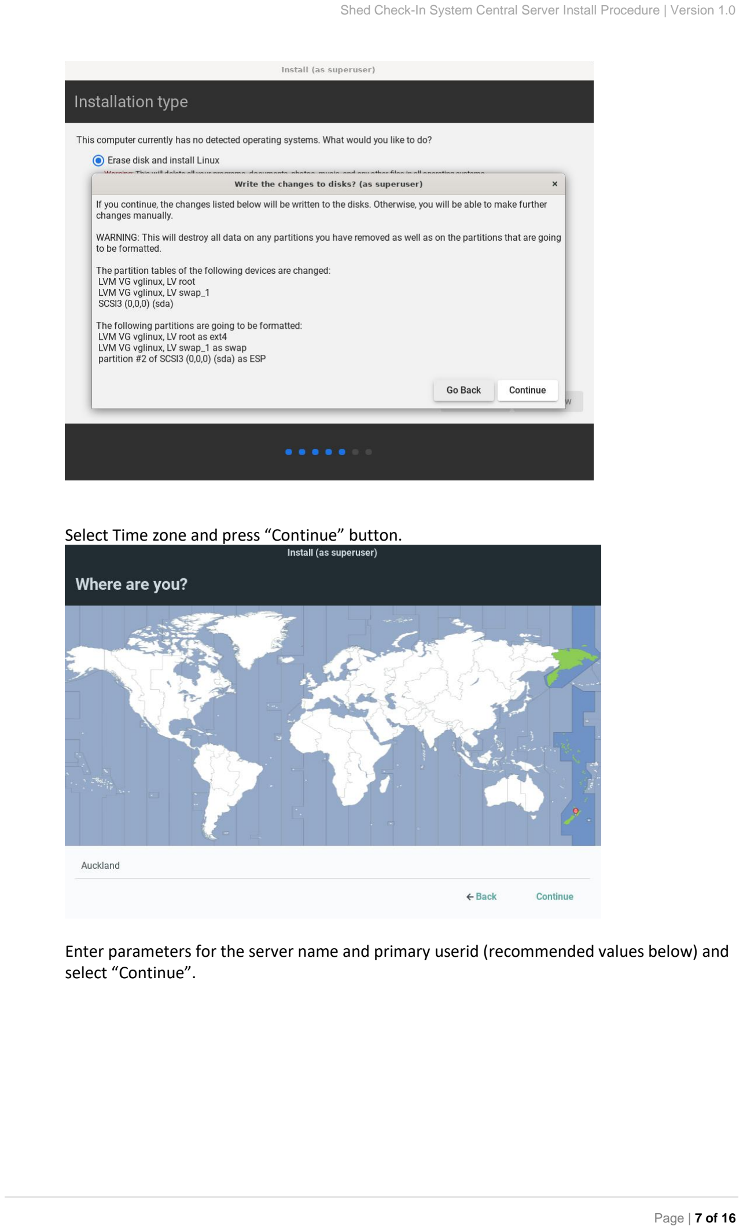
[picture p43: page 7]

Select Time zone and press “Continue” button.

Enter parameters for the server name and primary userid (recommended values below) and select “Continue”.


Recommended Values

Field | Value | Rationale
Your name | menzshed | The label to identify your userid as
Your computer’s name | menzshed-svr | The name of the computer
Pick a username | menzshed | The default user for the application to run on and to login as
Choose a password | [pick your own] | Something easy to remember, but complex enough not to guessed Do not use ‘*’ or ‘&’ or ‘/’.
Log in automatically | True | Don’t prompt for a password

Once the installation is complete, you will be prompted to restart. Click the “Restart Now” button.

After a short pause, you will be prompted to remove the install media, do so and press Enter key.


After the reboot is complete, you should see a screen where the menzshed userid is logged in.


### 1.6 Installation of Application

(These instructions will assume you have a windows computer with SFTP capability on the same network as the Server. The Central Server must still be capable of accessing the internet at this point.)

Start the console of the Server, and navigate to menu “Display”.


Select the resolution of 1920 x 1080 and select “Apply”. Confirm the resolution and Close the window.


At the console of the Server and start a terminal session (Icon on the bottom of screen)

Run the following commands to become the superuser “root” and enter the password for “menzshed” userid.

Install the package “openssh-server”. Answer “y” to any questions.

Once the installation is complete, open the /etc/ssh/sshd_config file for modification.

Change the line starting with “Subsystem” to read as follows. Press Control-X to exit and answer “y” to save the file.

Restart the sshd service and then confirm the IP address of the server with the “ip addr” command (this usually begins with 192.168.0 on the ‘inet’ line – below is an example only).

Using your remote computer, perform an SFTP connection to this IP address and upload the file “tmz_[version].tar.gz” to the directory /home/menzshed.

Swich back to the console of the Server and change to the directory /home/menzshed and unzip the file. (Values are example only).

After unzipping the file, change directory into TMZ_Bundle and look for a file named “setup_script.sh”. Run the following command and enter the required PIN for your site (your own choice).

You will then be prompted for an Organisation Name. This will be placed at the top of the screen and will be saved for future reference (like upgrades).

After a great deal of text scrolls past, you will be prompted which web server to configure. Press Space to select “apache2” then tab to move to the “OK” button and Space to continue.


After some more text scrolls through, you will be asked if you wish to configure the phpadmin package for the database. Use “Space” to select “Yes”.


You will be then asked to enter a password twice, for this integration. For ease of use, this password can also be used for the database password later on.

When prompted for a password for mysql, re-enter the phpadmin password.

You should see more text when database is created and customisations take place. The line “Script complete” indicates the install has completed.


### 1.7 Post Install Customisation

At this point, you have a basic install system, however you will need to customise it to continue.

Connect the Server to the designated router using a physical cable.

Reconfigure the network by starting the Network interface on the console by typing “network” in the search field and selecting “Network Connections”.


Highlight the connection shown, and select the Cog icon on the bottom of the screen.


Select the “IPV4” tab and select the Method of “Manual”.


Select the “Add” button and configure the network devices as below. Select “Save” and close down any other windows.


After reconfiguring the network, reboot the Server.

NOTE: Linux in general has changed the way networking is configured from Version 5 onwards. If your network change does not take effect, there are not enough column inches in this document to diagnose all the possible causes. Please research “nmcli” configuration and “Network Manager for linuxlite”, or post a question on their technical support forums.

Once the Host has rebooted, start the Web Browser and navigate to http://localhost/menzshed/ and then bookmark the page as your home page.


If you wish to customise your header, you can upload a small image into /var/www/html/menzshed/images/Logo.jpeg file and it will replace the crossed tools symbol that is default.

Appendix A – Control Server Hardware Recommendation and Costs

The following is the recommended Components, their Specification and Estimated Cost (as at Jul 2024, all figures in NZ Dollars)

Component | Description | Indicative Cost
Small Form Factor Computer | Dual Core Intel CPU, 8GB memory, 20GB Disk, USB ports, Min 1920x1080 resolution | $155 (Trademe NZ)
Keyboard | Standard USB Device
Mouse | Standard USB Device
Monitor | 1920x1080 resolution
Router | 1GB Router (can use old ISP router) | $20-$50 (Trademe NZ)
Network Cables | Ethernet Cat5/6, RJ-45 connections | $5-$10

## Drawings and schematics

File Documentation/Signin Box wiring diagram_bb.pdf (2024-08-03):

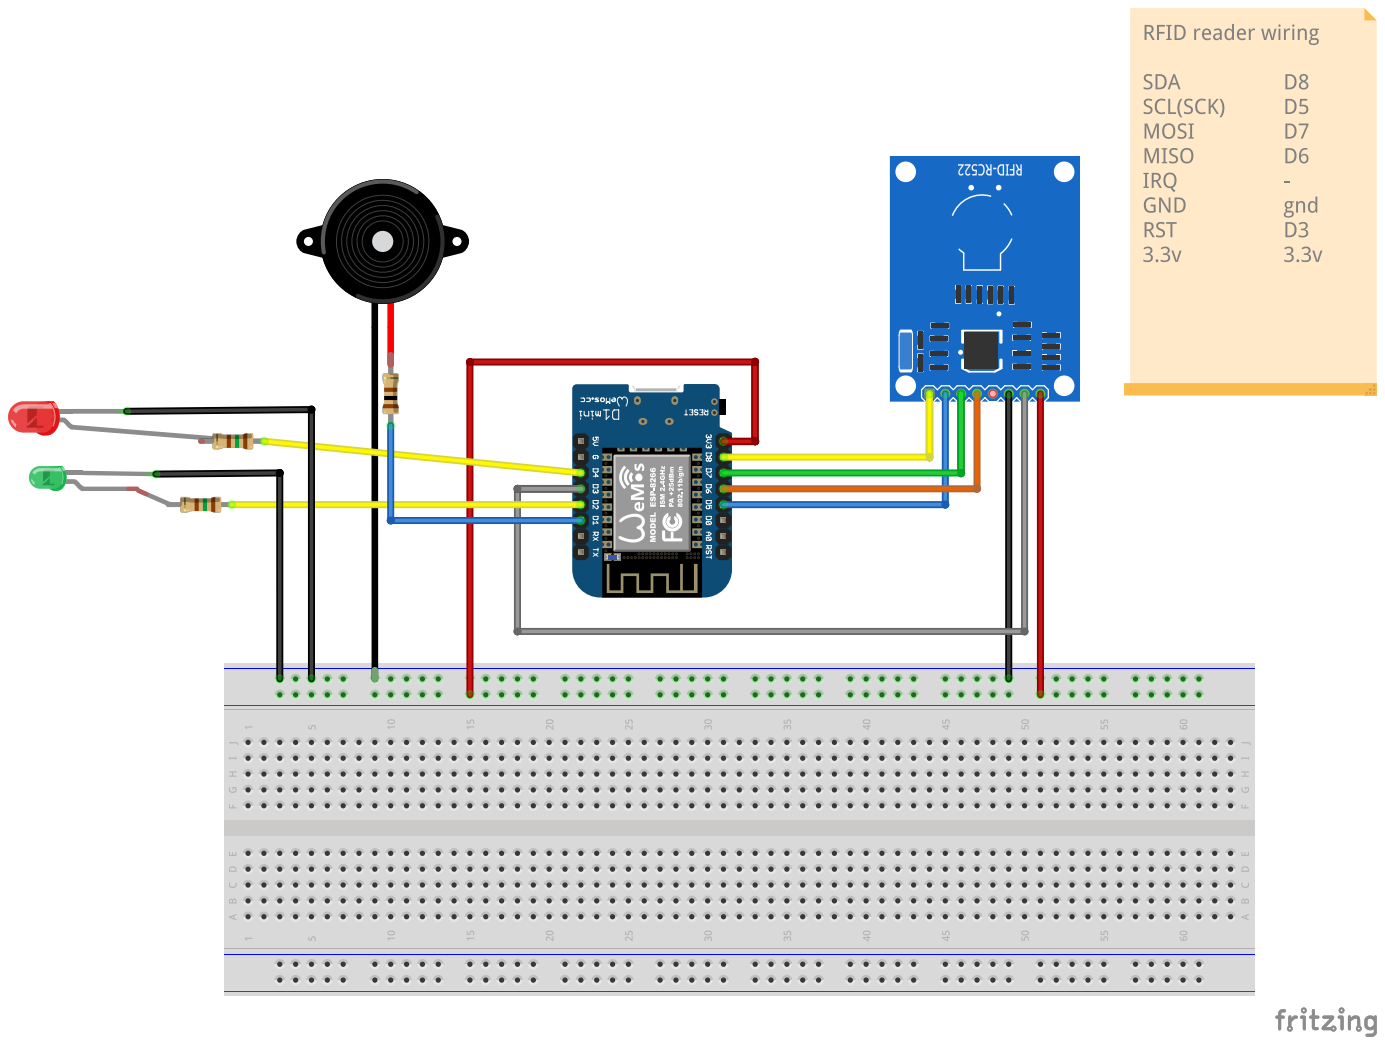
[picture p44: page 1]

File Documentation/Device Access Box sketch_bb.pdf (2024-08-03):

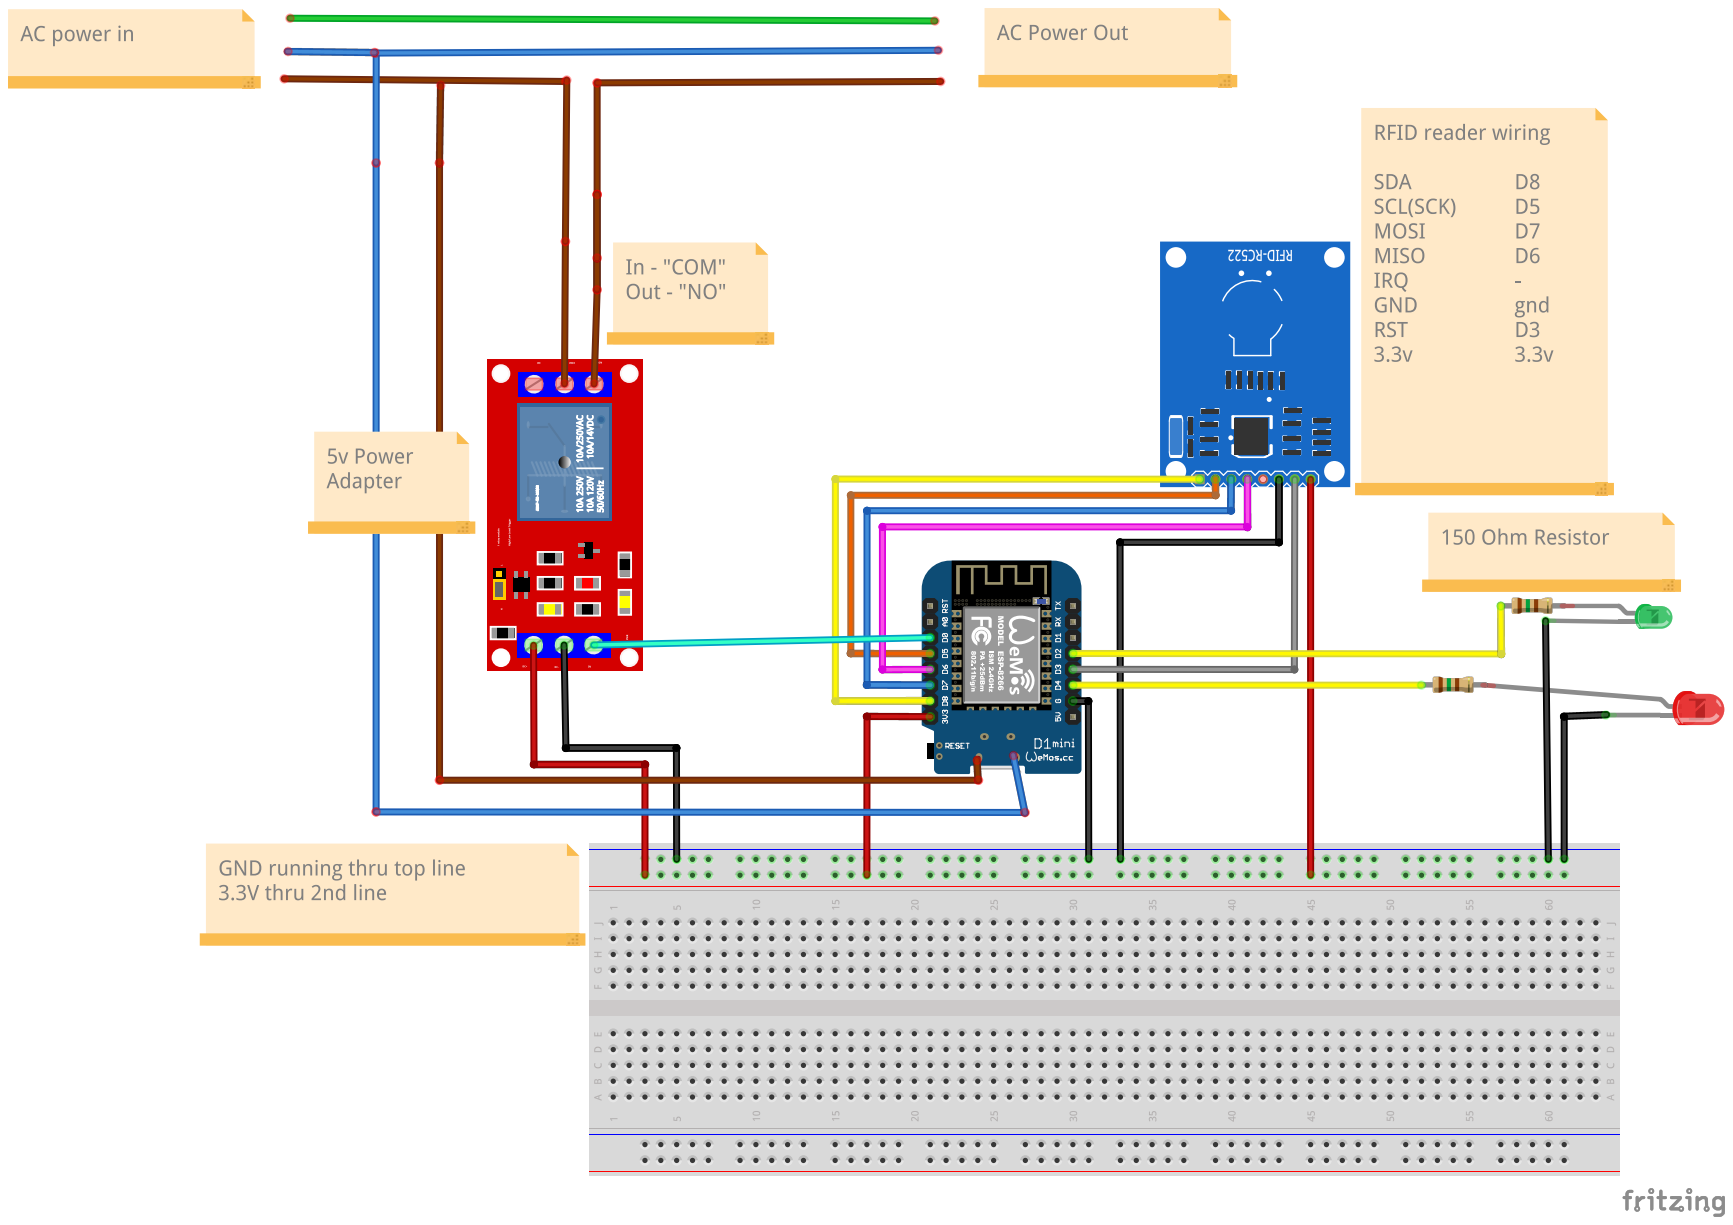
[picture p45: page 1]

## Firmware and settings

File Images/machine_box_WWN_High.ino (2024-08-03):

 /* 
 *  Board: NodeMCU 1.0 (ESP-12E Module)
 *  Program Name: machine_box_WWN_High

 *  Typical pin layout used:
 * ------------------------------------------------
 *             MFRC522      Arduino       Arduino   
 *             Reader/PCD   Uno/101       Mini     
 * Signal      Pin          Pin           Pin       
 * ------------------------------------------------
 * RST/Reset   RST          9             D3        
 * SPI SS      SDA(SS)      10            D8        
 * SPI MOSI    MOSI         11 / ICSP-4   D7        
 * SPI MISO    MISO         12 / ICSP-1   D6       
 * SPI SCK     SCK          13 / ICSP-3   D5
 * Buzzer      Blue                       D1
 * LED Green                              D2
 * LED Red                                D4
 * Relay                                  D0
 */

/* Version Control
* ----------------
* 5.2 - 5 Dec 2023 - Wait period after successful swipe on and off
* 5.3 - 27 Jan 2024 - Long ID (WWN) for registration 
* 5.3.1 - 22 Jun 2024 - Relay signal for activation of HIGH
*                     - swap initial signal and output setting
*/
#include <SPI.h>
#include <MFRC522.h>
#include <Wire.h>
#include <ESP8266WiFi.h>

//Menzshed ip address
IPAddress server(192,168,0,105);//address of mapped IP address

//Home IP Address
//IPAddress server(192,168,0,111);//address of mapped IP address

#define RST_PIN         D3          // Configurable, see typical pin layout above
#define SS_PIN          D8         // Configurable, see typical pin layout above

MFRC522 mfrc522(SS_PIN, RST_PIN);  // Create MFRC522 instance
MFRC522::MIFARE_Key key;

/* Define variables */
const String machine_id = "7"; // unique id of machine
String str_machine_wwn = "";

/* assign ports to component */
const int ledGreen = D2;
const int ledRed = D4;
//const int buzzer = D1;
const int relay = D0;
int counter;

/* WiFi variables */
const char ssid[]     = "insert_ssid_here";
const char password[] = "password";
const uint16_t port = 80;

boolean mach_in_use = false; //Machine in use status

unsigned long delayTime = 1800000; // 30 minutes in milliseconds

unsigned long timerMarker = 0;
unsigned long readerMarker = 0;

String cardUID;

void setup() {
  Serial.begin(115200);
  SPI.begin();      // Init SPI bus
  mfrc522.PCD_Init();         // Init MFRC522 card

  //initialise LEDs
  pinMode(ledRed, OUTPUT);
  pinMode(ledGreen, OUTPUT);

  // initialise buzzer
 // pinMode(buzzer, OUTPUT); // Set buzzer - pin 7 as an output
  
  //initialise Relay - sequence swapped
  digitalWrite(relay, LOW);
  pinMode(relay, OUTPUT);
  
//initiate the timer marker
  timerMarker = millis();
  readerMarker = millis();
  
// We start by connecting to a WiFi network

  Serial.println();
  Serial.println("Version: WWN_High");
  Serial.println();
  Serial.print("Connecting to ");
  Serial.println(ssid);

  /* Explicitly set the ESP8266 to be a WiFi-client, otherwise, it by default,
     would try to act as both a client and an access-point and could cause
     network-issues with your other WiFi-devices on your WiFi-network. */
  WiFi.mode(WIFI_STA);
  WiFi.begin(ssid, password);

  while (WiFi.status() != WL_CONNECTED) {
    flash();
    Serial.print(".");
  }

  Serial.println("");
  Serial.println("WiFi connected");
  Serial.println("IP address: ");
  Serial.println(WiFi.localIP());
  
  // Gather wwn machine_wwn
  byte myMac[6];
  WiFi.macAddress(myMac);
  // Loop around appending to strFull
  for (byte intX = 0; intX < 6; intX++) {
    // strWork=String(myMac[intX], HEX);
    // strFull.concat(strWork);
    // append 0 if only single digit
    if (myMac[intX] < 17)
    { str_machine_wwn+="0";}
        str_machine_wwn += String(myMac[intX], HEX);
     // Serial.printf("MYMAC:%i %i\n", intX, myMac[intX]);
    // Serial.printf("MYMAC:%i :%s:\n", intX, strWork);
     
    // Serial.printf("MYMAC_prog: %s\n", strFull);
  }
  Serial.printf("str_machine_wwn:");
  Serial.println(str_machine_wwn);
  Serial.printf("\n");
  //Ensure machine is logged out and ready for use
  // Use WiFiClient class to create TCP connections
  WiFiClient client;
  Serial.println("Closing off machine " + str_machine_wwn);
  client.connect(server, port);
  if (client.connected()) {
    //encode url
    String url = "/menzshed/api/machine/close_machine_long.php?machine_wwn=" + str_machine_wwn;
    Serial.println(url);
    client.println("GET " + url);
  }
  delay(100);
  ledRedOn();
  Serial.println("Setup complete for machine " + str_machine_wwn);
}


void loop() {

  RfidScan();
  //Green LED On (static) when in use
  if (mach_in_use){
    ledGreenOn();
  }
  //Red LED on when ready
  else {ledRedOn();}

  if ((millis()-timerMarker > delayTime) and mach_in_use){
    //force log off after 30 mins
    Serial.println("Forcing logoff");
    logOff("0");
  }

  //restart reader - this fixes the issue that it becomes unresponsive after a while
  if (millis()-readerMarker > 30000){
    Serial.println("Forcing erader reset");
    mfrc522.PCD_SoftPowerDown();
    delay(10);
    mfrc522.PCD_SoftPowerUp();
    mfrc522.PCD_Init();
    delay(4);
    readerMarker = millis();
  }
}

void RfidScan(){
    // Reset the loop if no new card present on the sensor/reader. This saves the entire process when idle.
  if ( ! mfrc522.PICC_IsNewCardPresent()) {
    return;
  }

  // Select one of the cards
  if ( ! mfrc522.PICC_ReadCardSerial()) {
    Serial.println("Card detected");
    return;
  }

  Serial.print(F("\nPICC type: "));
  MFRC522::PICC_Type piccType = mfrc522.PICC_GetType(mfrc522.uid.sak);
  Serial.println(mfrc522.PICC_GetTypeName(piccType));

  // Check is the PICC of Classic MIFARE type
  if (piccType != MFRC522::PICC_TYPE_MIFARE_MINI &&  
    piccType != MFRC522::PICC_TYPE_MIFARE_1K &&
    piccType != MFRC522::PICC_TYPE_MIFARE_4K) {
    Serial.println(F("Your q                                                                                         / is not of type MIFARE Classic."));
    return;
  }
  
  Serial.println(F("**Card Detected:**"));
  //printHex(mfrc522.uid.uidByte, mfrc522.uid.size);

  //save UID value
  cardUID = String(mfrc522.uid.uidByte[0],HEX) + " " + String(mfrc522.uid.uidByte[1],HEX) + " " + String(mfrc522.uid.uidByte[2],HEX) + " " + String(mfrc522.uid.uidByte[3],HEX);
  //upper case string
  cardUID.toUpperCase();
  //print Card UID
  Serial.println("\nCard UID: " + cardUID);

  //check if already logged on to machine
  if (!mach_in_use){
      //check member status against database
      if(webCallLong("check_long",cardUID)){
        //member is allowed to use the machine
        Serial.println("\nAccess allowed");
        logOn(cardUID);
      }
      else{
        //member is not allowed to use the machine
        Serial.println("\nMachine Access Denied");
        buzzerFailed();
      }
  }
  else{
    //machine is already in use on so can be logged off
    // will disable use of machine if user forgot to sign off and another comes along and tries to sign on
    logOff(cardUID);
  }
  
  // Wait so card can be removed- 1 second
  delay (1000);
  
  // Halt PICC
  mfrc522.PICC_HaltA();

  // Stop encryption on PCD
  mfrc522.PCD_StopCrypto1();
}

// Log on procedure of machine
void logOn(String tag_id){
  //set logged on flag
  mach_in_use = true;
  
  // add machine details to machine log table
  webCallLong("log_machine_long", tag_id);
  
  //open relay
  Serial.println("\nOpening Relay....");
  digitalWrite(relay, HIGH);

  //make successful sound
  //buzzerSuccessfull();
  //Turn Green LED On
  ledGreenOn();

  // reset timer
  timerMarker = millis();
  
  Serial.println("\nLogged on");
}

//Log off procedure
void logOff(String tag_id){
  //Log off
  mach_in_use = false;
  //close relay
  digitalWrite(relay, LOW);

  // log machine off in machine log table
  webCallLong("log_machine_long", tag_id);
  
  ledRedOn();
 
  Serial.println("\nLogged off");
}

/* Web Client procedures */
/*returns true if the member is allowed to use the machine */
boolean webCall(String page, String tag_id){
  boolean result = false;



  Serial.setTimeout(100);
  Serial.print("connecting to ");
  Serial.print(server);
  Serial.print(':');
  Serial.println(port);

  // Use WiFiClient class to create TCP connections
  WiFiClient client;
  if (!client.connect(server, port)) {
    Serial.println("connection failed");
    delay(5000);
    return false;
  }

  // This will send a string to the server
  Serial.println("sending data to server");
  if (client.connected()) {
    //encode url
    // String url = "/menzshed/api/machine/" + page + ".php?tag=" + urlencode(tag_id) + "&machinewwn=" + str_machine_wwn;
    String url = "/menzshed/api/machine/" + page + ".php?tag=" + urlencode(tag_id) + "&machine_id=" + machine_id;
    Serial.println(url);
    client.println("GET " + url);
  }

  // wait for data to be available
  unsigned long timeout = millis();
    while (client.available() == 0) {
    if (millis() - timeout > 5000) {
      Serial.println(">>> Client Timeout !");
      client.stop();
      delay(1000);
      return false;
    }
  }

  // Read all the lines of the reply from server and print them to Serial
  Serial.println("receiving from remote server");
 // String result=client.readString();
 // Serial.print("string received:%s\n", result);

  while (client.available()) {
     char answer = static_cast<char>(client.read());
     Serial.print(answer);
     if (answer == '1'){
      result = true;
     }
  }

  // Close the connection
  Serial.println();
  Serial.println("closing connection");
  client.stop();
  
  return result;
}

boolean webCallLong(String page, String tag_id){
  boolean result = false;
  Serial.setTimeout(100);
  Serial.print("connecting to ");
  Serial.print(server);
  Serial.print(':');
  Serial.println(port);

  // Use WiFiClient class to create TCP connections
  WiFiClient client;
  if (!client.connect(server, port)) {
    Serial.println("connection failed");
    delay(5000);
    return false;
  }

  // This will send a string to the server
  Serial.println("sending data to server");
  if (client.connected()) {
    //encode url
    // String url = "/menzshed/api/machine/" + page + ".php?tag=" + urlencode(tag_id) + "&machine_wwn=" + str_machine_wwn;
    String url = "/menzshed/api/machine/" + page + ".php?tag=" + urlencode(tag_id) + "&machine_wwn="+ str_machine_wwn;
    Serial.println(url);
    client.println("GET " + url);
  }

  // wait for data to be available
  unsigned long timeout = millis();
  // unsigned long timeout = micros();
  while (client.available() == 0) {
    if (millis() - timeout > 5000) {
      Serial.println(">>> Client Timeout !");
      client.stop();
      delay(1000);
      return false;
    }
  }

  // Read all the lines of the reply from server and print them to Serial
  Serial.println("receiving from remote server");

   // trial 1 - readsting
  // String resultBack=client.readString();
 // delay(100);
 
  // trial 2 - serial.read
  //String resultBack="";
  //while (Serial.available()) {
  //  char c = Serial.read();  //gets one byte from serial buffer
  //  resultBack += c; //makes the String readString
  //  delay(2);  //slow looping to allow buffer to fill with next character
  //}

  // trial 3 
  //     String resultBack[20];
  //      unsigned long timeout2 = millis() + 1000;
  //      uint8_t inIndex = 0;
  //      while ( ((int32_t)(millis() - timeout2) < 0) && (inIndex < 2)) {
  //          if (Serial.available() > 0) {
  //              // read the incoming byte:
  //              // resultBack[inIndex] = Serial.read();
  //              char c = Serial.read();
  //              if ((c == '\n') || (c == '\r')) {
  //                  break;
  //              }
  //              printf(".%c", c);
  //              resultBack[inIndex++]=c;
  //              Serial.write(c);
  //          }
  //      }

  // trial 4 - readstring with timeout
  //  String resultBack=client.readString();
  // delay(100);
 
 // trial 5 - use read but read from "client."" not "Serial."
     String resultBack[20];
     unsigned long timeout2 = millis() + 1000;
     uint8_t inIndex = 0;
     while ( ((int32_t)(millis() - timeout2) < 0) && (inIndex < 2)) {
         if (client.available() > 0) {
                // read the incoming byte:
               // resultBack[inIndex] = Serial.read();
              char c = client.read();
              if ((c == '\n') || (c == '\r')) {
                   break;
              }
              printf(".%c", c);
              resultBack[inIndex++]=c;
              Serial.write(c);
            }
        }
 
  Serial.printf("string received:");
  Serial.printf("%s", resultBack);
//  Serial.printf("%s", inData);
  Serial.printf(":\n");
   
  // Send back first character
  if ( resultBack[0] == "1")
  {
   result = true;
  } else
  { result = false;
  }
 // while (client.available()) {
 //    char answer = static_cast<char>(client.read());
 //    Serial.print(answer);
 //   if (answer == '1'){
 //     result = true;
 //    }
 // }
  
  // Close the connection
  Serial.println();
  Serial.println("closing connection");
  client.stop();
  
  return result;
}
// URL encoding procedure
String urlencode(String str)
{
    String encodedString="";
    char c;
    char code0;
    char code1;
    
    for (int i =0; i < str.length(); i++){
      c=str.charAt(i);
      if (c == ' '){
        encodedString+= '+';
      } else if (isalnum(c)){
        encodedString+=c;
      } else{
        code1=(c & 0xf)+'0';
        if ((c & 0xf) >9){
            code1=(c & 0xf) - 10 + 'A';
        }
        c=(c>>4)&0xf;
        code0=c+'0';
        if (c > 9){
            code0=c - 10 + 'A';
        }
        
        encodedString+='%';
        encodedString+=code0;
        encodedString+=code1;
        
      }
      yield();
    }
    return encodedString;
}

/**
 * Helper routine to dump a byte array as hex values to Serial.
 */
void printHex(byte *buffer, byte bufferSize) {
  for (byte i = 0; i < bufferSize; i++) {
    Serial.print(buffer[i] < 0x10 ? " 0" : " ");
    Serial.print(buffer[i], HEX);
  }
}

// LED procedures
void flash(){
  //Red light on
  digitalWrite(ledRed, HIGH);
  delay(300);
  //Red light off
  digitalWrite(ledRed, LOW);
  //Green light on
  digitalWrite(ledGreen, HIGH);
  delay(300);
  //Green light off
  digitalWrite(ledGreen, LOW);
}

void ledGreenOn(){
  //turn off Red LED
  digitalWrite(ledRed, LOW);
  //turn on Green LED
  digitalWrite(ledGreen, HIGH);
}

void ledGreenFlash(){
  static unsigned long lastBlinkTime = 0;
  if (millis() - lastBlinkTime >= 500UL)
  {
    digitalWrite(ledGreen, !digitalRead(ledGreen)); //toggles the led
    lastBlinkTime = millis();
  }
}

void ledRedOn(){
  //turn off Green LED
  digitalWrite(ledGreen, LOW);
  //turn on Red LED
  digitalWrite(ledRed, HIGH);
}

//Buzzer procedures
void buzzerFailed(){
  //sound buzzer and flash red LED
  //tone(buzzer, 400, 250);
  digitalWrite(ledGreen, LOW);
  digitalWrite(ledRed, HIGH);
  delay(100);
  digitalWrite(ledRed, LOW);
  delay(100);
  digitalWrite(ledRed, HIGH);
  delay(100);
  digitalWrite(ledRed, LOW);
  
  //tone(buzzer, 250);
  delay(100);
  digitalWrite(ledRed, HIGH);
  delay(100);
  digitalWrite(ledRed, LOW);
  delay(100);
  digitalWrite(ledRed, HIGH);
  delay(100);
  digitalWrite(ledRed, LOW);
  delay(100);
  digitalWrite(ledRed, HIGH);
  //noTone(buzzer);
}
